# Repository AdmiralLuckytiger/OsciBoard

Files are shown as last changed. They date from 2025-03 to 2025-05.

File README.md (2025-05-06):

# __OsciBoard__: Wein Bridge Oscillator

<p align=center>
  
</p>

## 👋 Welcome

This repository walks you through the design, build, and testing process of a Wien Bridge Oscillator.

Inside, you'll find the steps we followed to bring the project to life, along with additional thoughts and notes added along the way. Since this has been an iterative process, we’ve included reflections and improvements made throughout the journey.

## 🎯 Objective

The goal of this project is to design and implement a sinusoidal oscillator operating at 10 kHz. To achieve this, we’ve chosen a classic Wien Bridge Oscillator as our base circuit. From there, the signal will be enhanced using a variable gain stage to improve performance and stability.

To analyze the oscillator’s output, we’ll be using a digital system. This means the signal needs to be conditioned and digitized before processing. For digitization, we'll use the ADC (Analog-to-Digital Converter) integrated in a System on Chip (SoC). This SoC includes:

- A programmable logic section (FPGA)

- Two microprocessors

Because of this setup, the oscillator's output voltage must remain within the 0 to 3.3V range to be safely read by the ADC. Protective measures will also be implemented to prevent any out-of-range voltages.

Once the signal is digitized, we aim to measure two key parameters:

- The frequency of the oscillation

- The amplitude of the waveform

The frequency value will be displayed on a 7-segment display connected via a shield to the development board.

## 🧪 Simulations
In this section, we describe the proposed system in more detail—breaking down the main stages and showing how we simulated each part. 

### 💡 Solution Overview
> [!IMPORTANT]
> We're required to use a Wien Bridge Oscillator as a constraint of this project.
> Fortunately, this type of oscillator is a great fit for our goals—it’s inexpensive, well-suited for our frequency range, and has a smooth startup behavior.

Our solution is built around a Wien Bridge Oscillator with adjustable gain. The oscillator generates a sinusoidal signal that is sent to two separate subcircuits:

---

### 🔎 Subcircuit 1: Frequency Measurement Path

This branch of the circuit is responsible for preparing the signal so that its frequency can be measured digitally: 

- First, a summing amplifier introduces an offset and scales the signal.

- Then, an inverting amplifier corrects the polarity, resulting in a signal fully within the positive range.

Together, these stages ensure the signal is properly conditioned for reliable digital processing.

---

### 🔎 Subcircuit 2: Amplitude Measurament Path

This second branch is dedicated to measuring the amplitude of the oscillation: 

- A precision full-wave rectifier caaptures the full waveform.

- This is followed by a two-pole low-pass filter, which smooths the signal to provide a stable DC value that reflects the original amplitude.

> [!WARNING]
> In this kind of project, where we're working with signals that carry important information, it's essential to use precision rectifiers—other types can significantly alter the signal. 

The solution we chose is based on generating two separate signals—one for measuring amplitude and the other for frequency. While this approach was selected somewhat arbitrarily, it gives us a great opportunity to implement and experiment with different circuits along the way.

> [!CAUTION]
> We could have gone with a normalized filter, like a Chebyshev filter. However, since we're not working in a restrictive environment and the only key requirement is unity gain, we chose this particular design. In the lab, other topologies ran into some issues with maintaining the correct gain. That said, future improvements could definitely benefit from using normalized filters for better performance.

<p align="center">
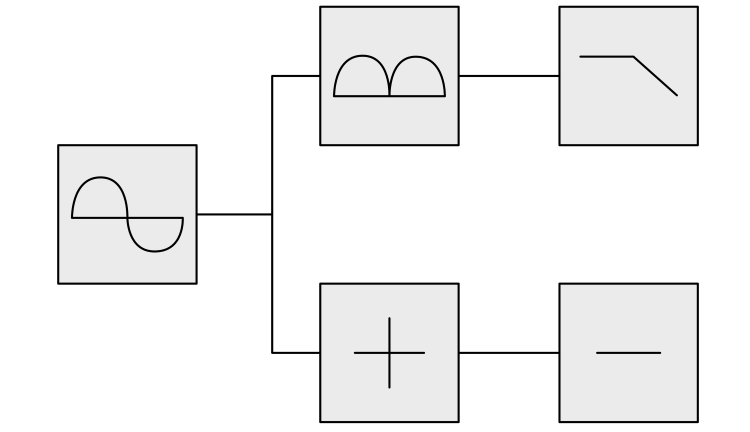
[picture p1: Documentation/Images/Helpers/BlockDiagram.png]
  
</p>

### 🖥️ Simulation Enviorament 

The entire system was simulated using LTSpice, a tool provided for free by Analog Devices. We chose LTSpice as our main simulation environment because it's free and includes most of the component models we’re using out of the box.

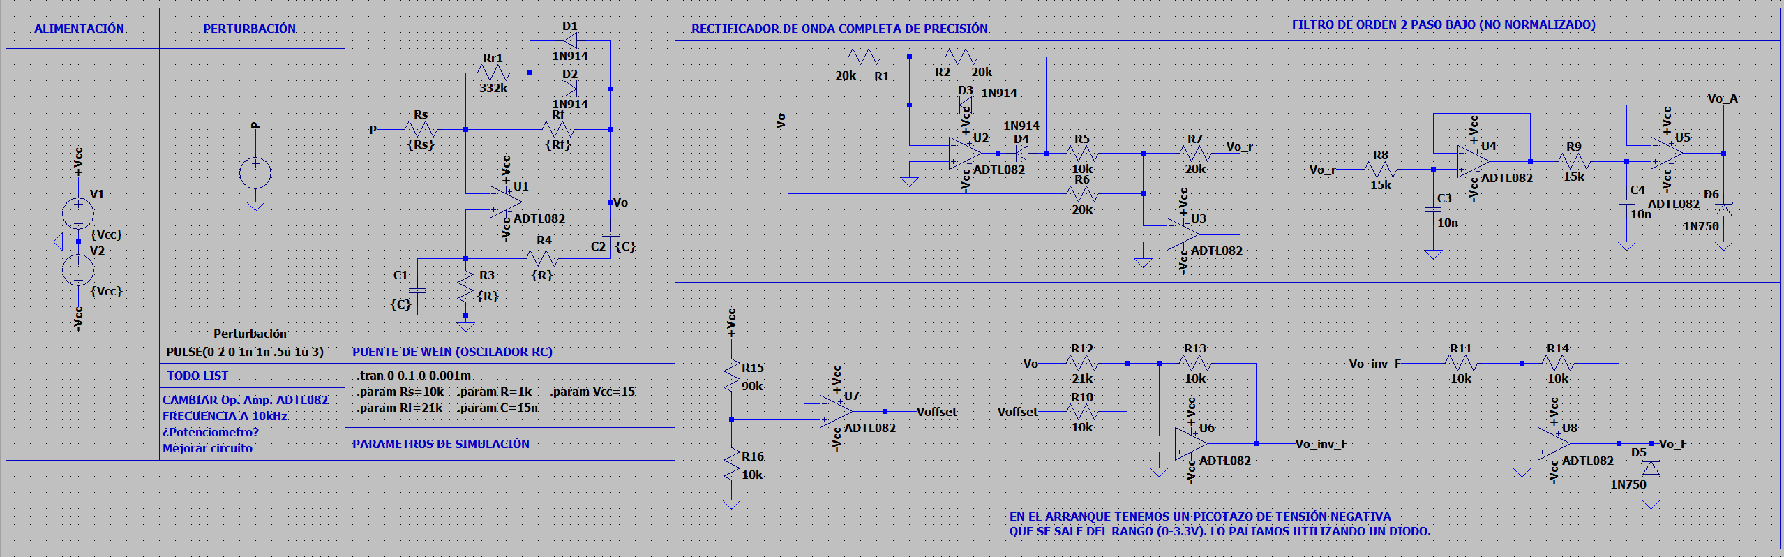
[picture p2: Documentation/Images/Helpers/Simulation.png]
Simulation Schema


> [!NOTE]
> The component values used in the simulation were selected through a combination of theoretical calculations and manual tuning. The theory we applied comes from "Fundamentals of Electronics: Oscillators and Advanced Electronics Topics."

### 🧾 Results

We identified three critical signals in the system:

- The output of the Wien Bridge Oscillator
- The frequency output signal
- The amplitude output signal

The simulation results for these signals are consistent with theoretical expectations.

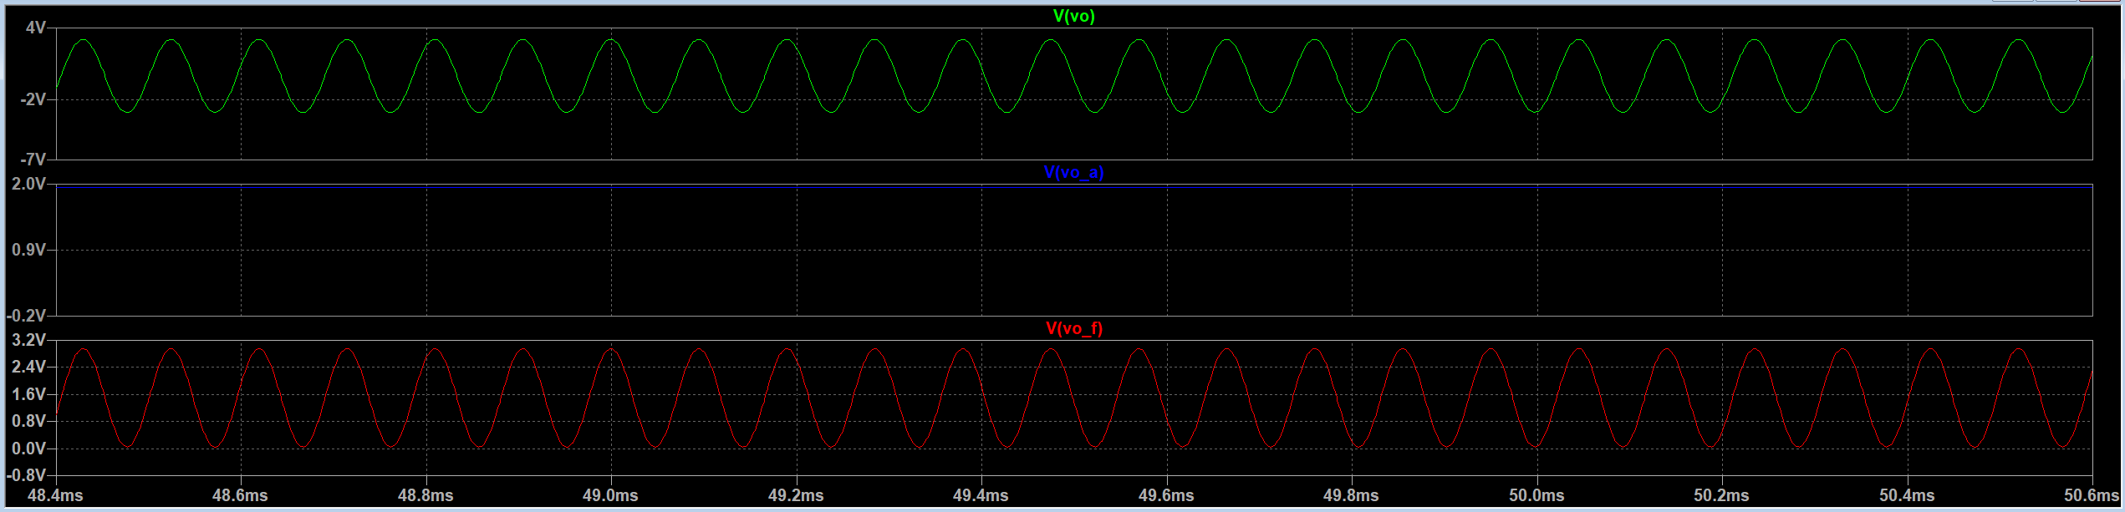
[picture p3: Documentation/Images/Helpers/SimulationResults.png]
Simulation Results


> [!NOTE]
> Beyond these main signals, the simulation also provided valuable insights through intermediary signals. These will be especially helpful when debugging the real-world circuit.

## 👨‍🔬 Lab Tests
Once the simulation was completed and validated according to the project specifications, we moved on to testing the core building blocks of our system. A full system test would have required significantly more time and resources, and the errors we could catch with a complete system weren’t considered critical. 

> [!NOTE]
> In our first approach, we focused only on testing the Wien Bridge Oscillator. However, this decision led us to miss some issues in the full-wave precision rectifier block before sending the schematics out for fabrication. That ended up being a mistake and taught us a valuable lesson—future projects should definitely include testing of all critical blocks early on.

### ✅ Wein Bridge Oscillator

Wein Bridge Oscillator

Without the variable gain circuit, the oscillator output was saturated and had no amplitude control, which made it unusable in its initial form.

### ✅ Full Wave Precission Rectifier

> [!NOTE]
> Our first version of this block used standard diodes, which introduced distortion into the signal. We solved this issue by switching to Schottky diodes with a fast recovery time, which worked much better in this case.

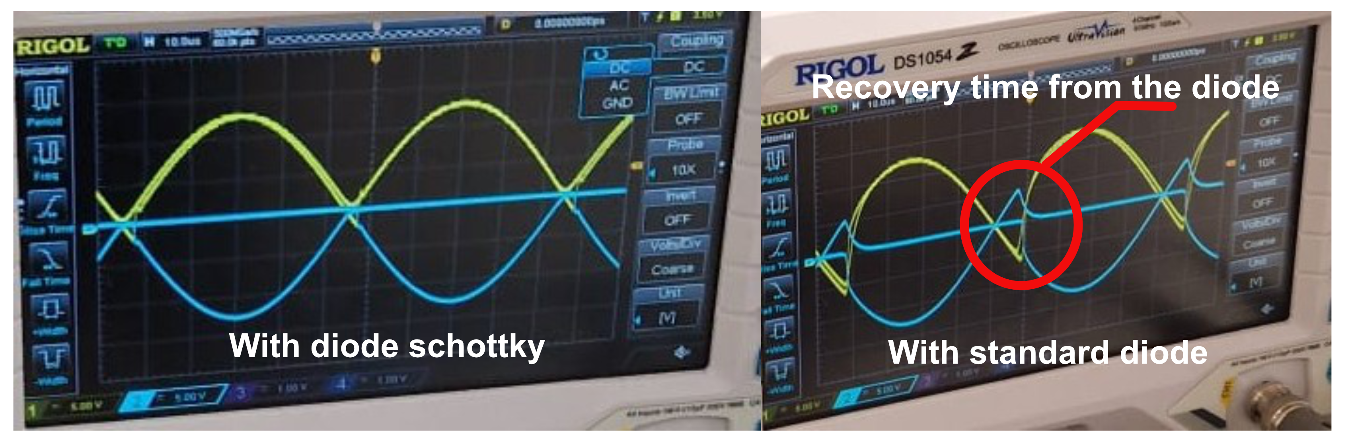
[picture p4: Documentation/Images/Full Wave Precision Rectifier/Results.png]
Rectifier


## ▶️ PCB Design
This step was developed in parallel with the lab testing phase. We chose KiCad 8 for the PCB design because it’s a user-friendly tool that fits well with the scope of our project.

> [!NOTE]
> While KiCad’s documentation is excellent, we also used the book "Design an RP2040 Board with KiCad" as our primary guide throughout the design process.
---
### ✅ Schematics
We translated the schematics from our simulation into KiCad's tool. This step also gave us the opportunity to:

- Annotate key design aspects
- Select the appropriate component footprints, which helped with our component selection
- Approach the project more formally

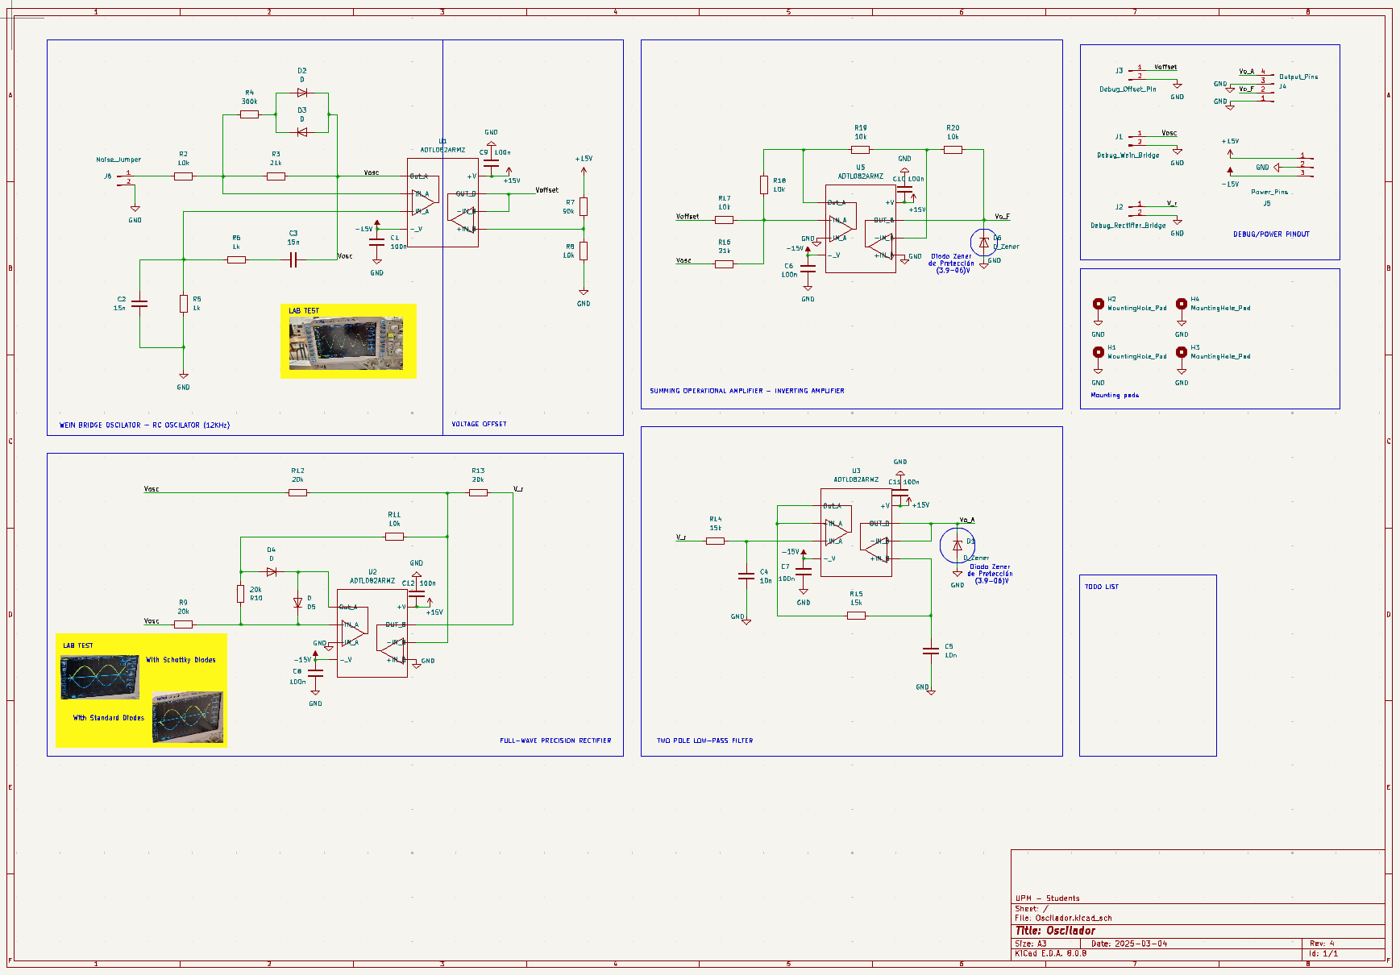
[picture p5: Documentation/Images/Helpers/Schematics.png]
Genenral Schematic

---
### ✅ Layout
The PCB layout is just as important as the schematics. For this part, we took an iterative approach, making small improvements and corrections with each step.

We added as many debug pins as possible to improve the system's observability. 

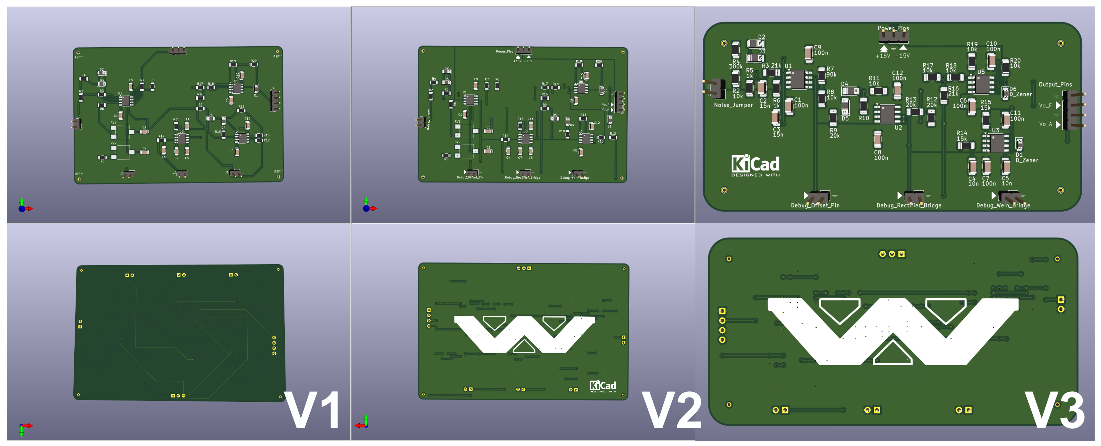
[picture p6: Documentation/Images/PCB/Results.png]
Layout


> [!CAUTION]
> A mistake worth highlighting is our use of non-standard debug pins. This could potentially cause short circuits when measuring with oscilloscope probes. In future designs, we’ll use standard debug pin layouts to make debugging easier and safer. 

> [!NOTE]
> Before starting the layout, it’s important to consider the manufacturer’s capabilities. Certain design parameters, such as trace width or via size, may be limited by the manufacturer, so it's a good idea to choose them early in the process.

We also made use of flooded zones, which helped with power pin connections and provided some shielding for noise-sensitive components.

> [!NOTE]
> In future designs, we plan to avoid placing vias on the component pads, as it negatively affects the quality of solder connections.
---
### ✅ Components Selection
Since we’re hand-soldering the components ourselves, we limited our selection to standardized 1206 and 0805 footprints, which are easier to solder manually. 

> [!IMPORTANT]
> When working with circuits where component values are critical, we recommend testing a range of values. Despite validating component values on a breadboard, one of our resistors had a tolerance issue in the final PCB version, which caused the Wien Bridge Oscillator to fail. This issue wasn’t caught until after over eight hours of debugging—a painful lesson that we hope to avoid in future projects. 
---
#### 💰 Purchase
For simplicity, we sourced all our components from a single electronics shop.

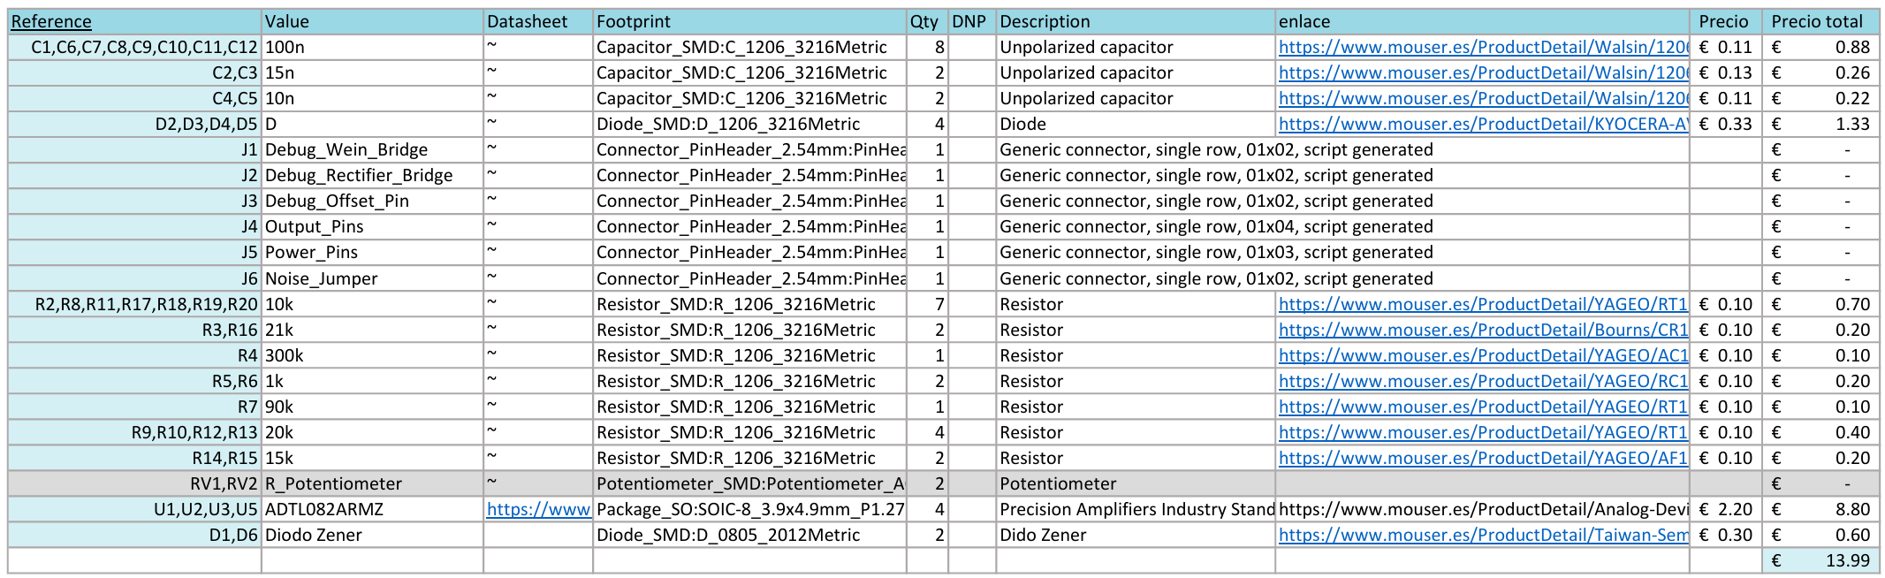
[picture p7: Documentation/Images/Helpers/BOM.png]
BOM


> [!NOTE]
> Before making any purchases, make sure the shop handles taxes. It can save you from unexpected costs down the road. 

## 🎉 Results
In the following images, you can see the board being tested. 

Lab Results

---

## 🧠 Digital Circuit Overview

A core component of this project is the development of a custom digital circuit deployed on the PYNQ-Z2 development board. This circuit is responsible for measuring and displaying the frequency of an input signal. It operates synchronously using the board’s external 125 MHz clock source.

### ⚙️ Core Functional Blocks

- **XADC**  
  The Xilinx Analog-to-Digital Converter (XADC) is used to sample the analog input signal. The IP core is configured to operate at 1 MSPS (Mega Samples Per Second), which provides sufficient resolution to support the frequency measurement system.

- **Frequency Counter**  
  A dedicated module counts the number of signal transitions (edges) within a fixed time window of 0.1 seconds. This interval allows us to display the frequency in kilohertz (kHz) with two decimal places of precision.

- **Binary to Binary-Coded Decimal (BCD) Converter**  
  To prepare the computed frequency value for display, a binary-to-BCD converter is implemented using the Double Dabble algorithm. This conversion is necessary for driving human-readable outputs like 7-segment displays.

- **Display Interface**  
  The BCD-encoded frequency value is passed to a display driver that outputs it via 7-segment displays, allowing for visualization of the measured frequency.

---

### 📊 Simulation Results

Below are visual results from the simulations of each key subcircuit in the system. These illustrate the signal's journey from digitization to binary-coded decimal (BCD) conversion.

#### 🔍 XADC (Analog-to-Digital Conversion)

This image shows the output of the XADC operating at 1 MSPS with 100 samples per point. It represents the digitized version of the input analog signal.

<p align="center">
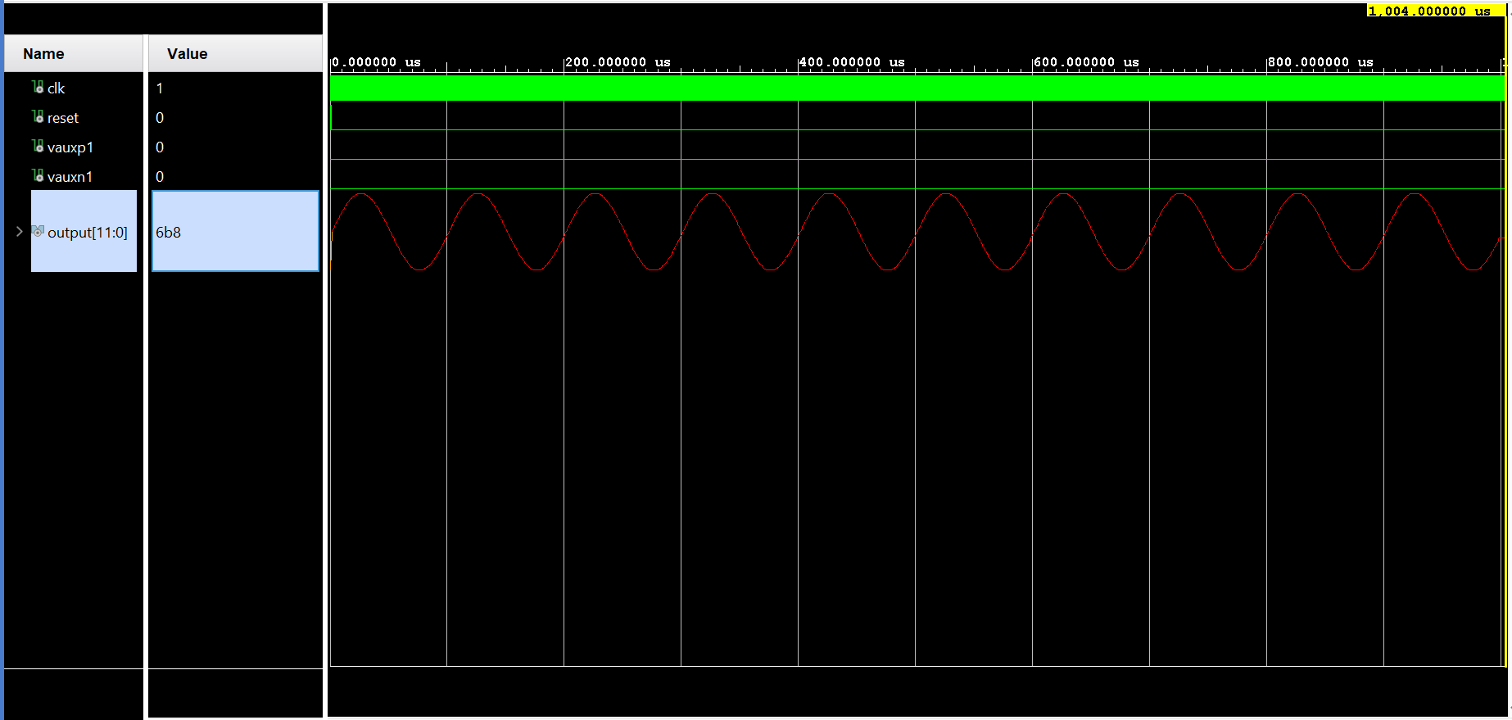
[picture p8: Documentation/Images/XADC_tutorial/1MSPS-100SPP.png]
  
</p>

#### 📟 Frequency Counter

These simulations depict the frequency counter circuit in action. The first image shows the primary frequency counting logic, while the second provides a complementary perspective of the counter’s operation.

<p align="center">
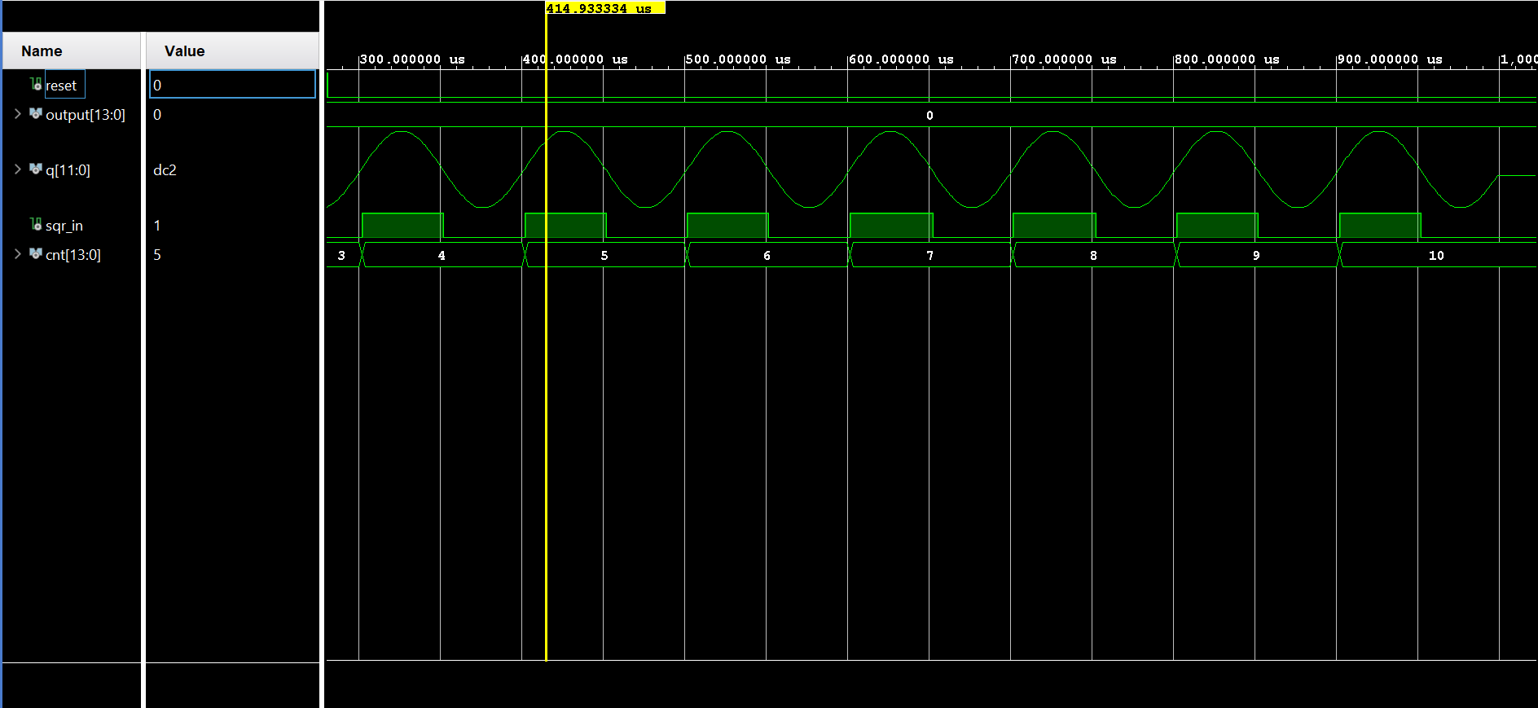
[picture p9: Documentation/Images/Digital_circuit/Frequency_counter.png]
  
</p>

<p align="center">
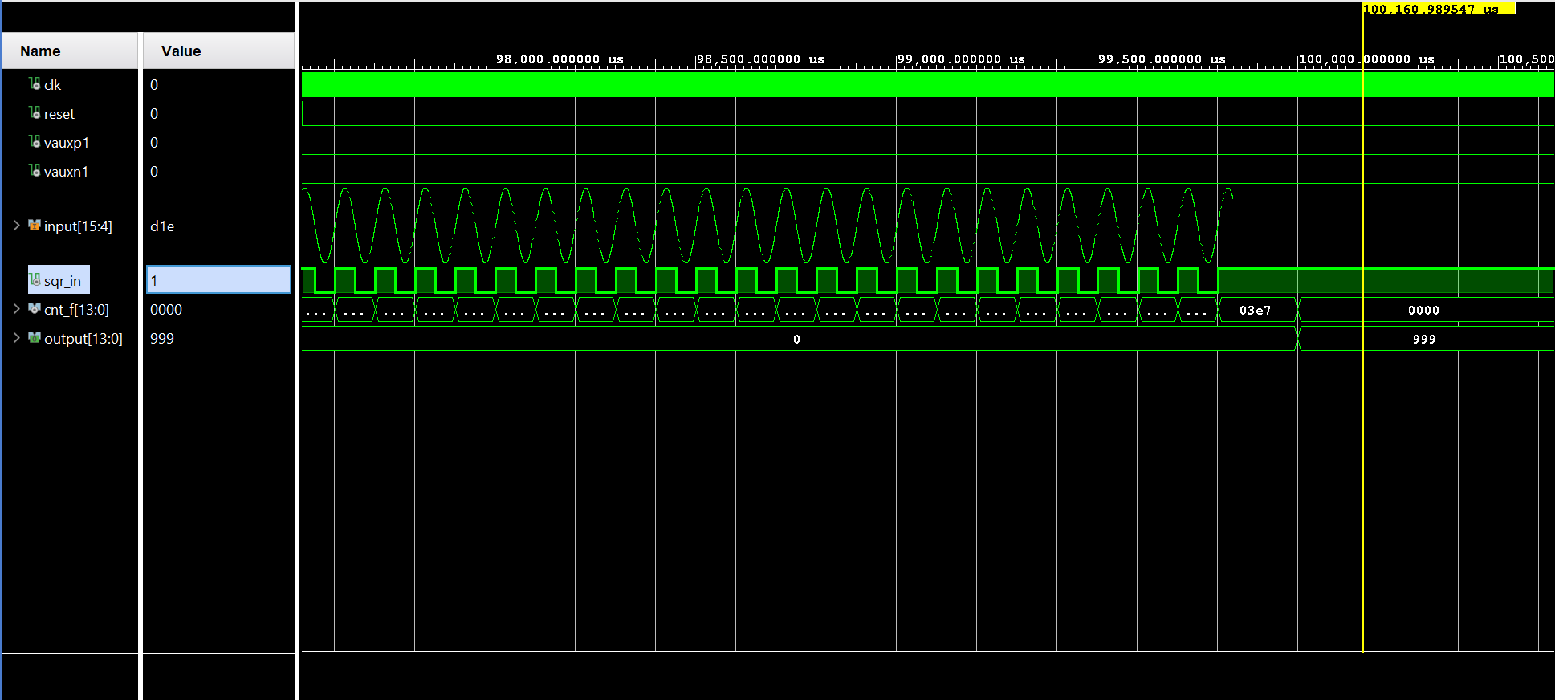
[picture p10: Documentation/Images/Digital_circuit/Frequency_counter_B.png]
  
</p>

#### 🔢 Binary to BCD Conversion

Finally, the image below demonstrates the output of the binary to BCD converter. This is the final step in the digital signal processing pipeline, converting the raw binary frequency value into a human-readable decimal format.

<p align="center">
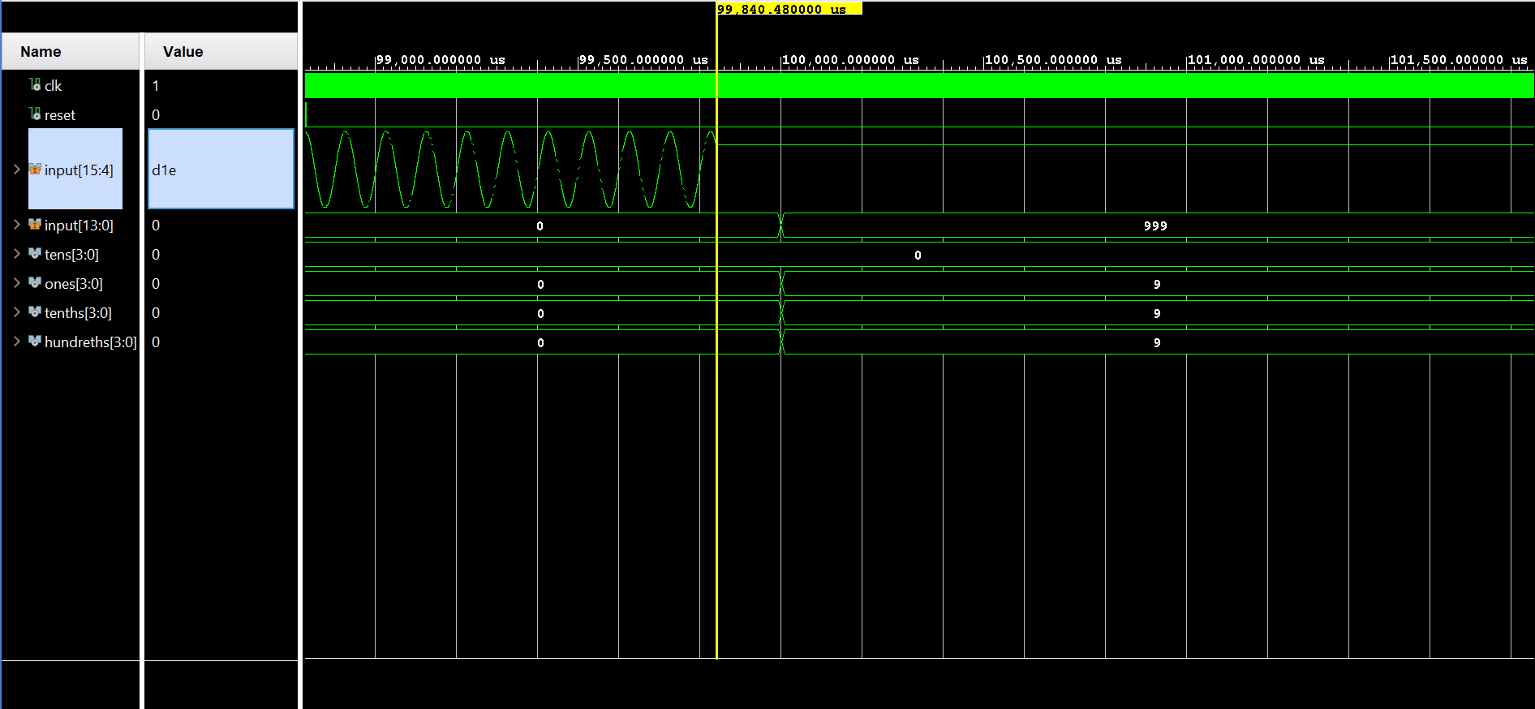
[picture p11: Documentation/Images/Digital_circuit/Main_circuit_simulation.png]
  
</p>

---

### 💡 Additional Notes

This system is entirely implemented in VHDL and synthesized using Xilinx Vivado. For detailed implementation instructions, configuration parameters, and deployment steps, refer to the [project documentation](./Prototype/Vivado/README.md).

---

## 🎉 Results 

The image below showcases our digital circuit in action, measuring the frequency of a sinusoidal signal generated by the Wien Bridge oscillator board.

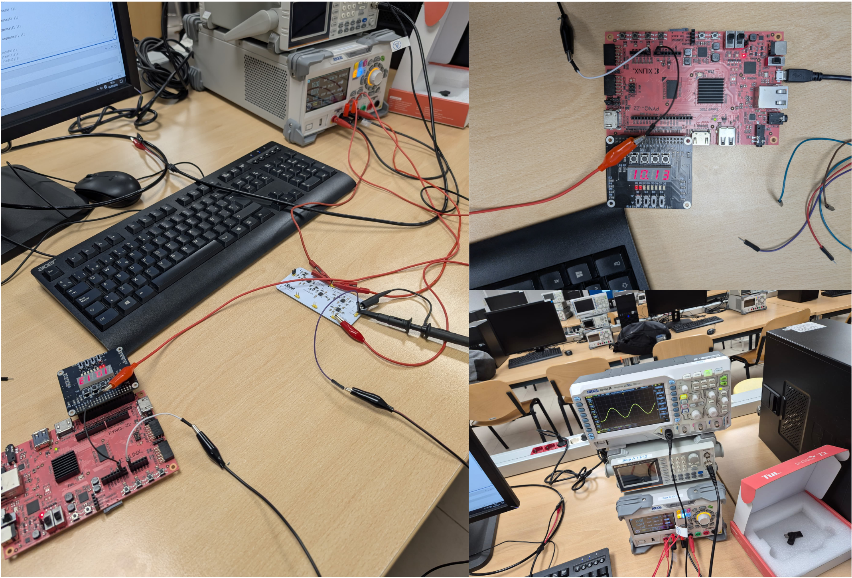
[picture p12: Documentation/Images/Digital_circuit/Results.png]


In this setup, the Wien Bridge oscillator produces a stable sine wave, which is then processed by our digital circuit to determine its frequency.

As a final note, we would like to highlight the success of integrating both digital and analog circuitry in our project. This experience has provided us with invaluable insights into working across both domains, and has significantly increased our confidence in designing and implementing mixed-signal systems.

That said, throughout the development process, we also identified areas for improvement and noted several design mistakes that can be corrected in future iterations. These lessons will be crucial for refining our approach and achieving even better results in upcoming projects.

---

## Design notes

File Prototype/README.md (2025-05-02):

### 📁 Project Files Overview

In this folder, you will find the primary prototype files created using **KiCad 8**. These files can be used to generate the necessary **Gerber files** required for PCB manufacturing.

Additionally, the folder includes:

* 💡 **Digital circuit design source files** – Schematics and layouts for the digital components of the project.
* 🧪 **Testbenches** – Simulation files used to verify the behavior and performance of individual subcircuits.

These resources collectively support both the hardware prototyping and digital logic development aspects of the project.

---

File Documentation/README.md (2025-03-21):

# Main documentation
In this folder you can find different versions of the schematics of the proyect, images and the request with which we start the proyect.

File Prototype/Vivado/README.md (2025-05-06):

# 🧭 Digital Circuit Design

Before jumping into implementation, it's essential to address a few design questions that guide our development choices. These questions will help shape the architecture of the digital circuit and ensure it meets performance and usability expectations.

---

## 🧠 How will we measure the frequency of the sinusoidal signal from the XADC?

The XADC (Xilinx Analog-to-Digital Converter) gives us a digitized version of the input analog signal. However, to determine the frequency, we must process that data further.

A straightforward and effective method is to use a [frequency counter](https://andybrown.me.uk/2016/02/21/nanocounter/). The idea is to:

- Convert the analog sinusoid to a square wave (e.g., by thresholding).
- Count the number of cycles of the square wave in a given time frame.
- Compare this with a known clock signal to compute frequency.

This approach is hardware-friendly and works well in real-time digital systems.

> [!WARNING]
> When using the XADC, be careful with the pins you select. Take the time to thoroughly check the schematics of your specific board and consult the official constraints file. Sometimes, pin names can be misleading.

---

## 🔢 How do we display binary numbers on 7-segment displays?

The frequency counter outputs binary values that aren't human-readable in their raw form. To make these values suitable for display, we’ll convert them into [Binary-Coded Decimal (BCD)](https://en.wikipedia.org/wiki/Binary-coded_decimal).

BCD makes it easier to display numbers on standard 7-segment displays, which are designed for decimal digits.

### Conversion Method

To perform this conversion in hardware, we use the [Double Dabble algorithm](https://en.wikipedia.org/wiki/Double_dabble). It's a simple and effective way to convert binary values into BCD, with low resource usage — perfect for FPGA implementation.

The output will then drive four 7-segment displays, allowing easy real-time monitoring.

---

## ⏱️ What sampling rate do we need?

We are working with a signal approximately **10 kHz** in frequency. To capture the waveform accurately:

- **Minimum sampling rate:** 20 kHz (according to the **Nyquist Theorem**).
- In practice, a higher rate (e.g., 50–100 kHz) might be used to improve accuracy and reliability.

> [!NOTE]  
> **Nyquist Theorem**  
> If a function contains no frequencies higher than BW Hz, it is completely determined by samples taken every 1/(2BW) seconds.

Beyond the basic concept of sampling frequency, it's important to emphasize that, for our frequency counter, we require the highest possible number of samples per second. This is crucial because we need to accurately capture the smooth transitions of the signal, especially as it crosses our reference threshold of 1.5V (the virtual ground or zero reference).

Accurate detection of these transitions is essential for reliable frequency measurement. A higher sampling rate allows us to pinpoint the exact moments when the signal crosses the reference voltage, minimizing errors due to aliasing or missed transitions.

In the following images, we compare different sampling scenarios to illustrate the challenges and implications of insufficient sampling resolution. 

<p align="center">
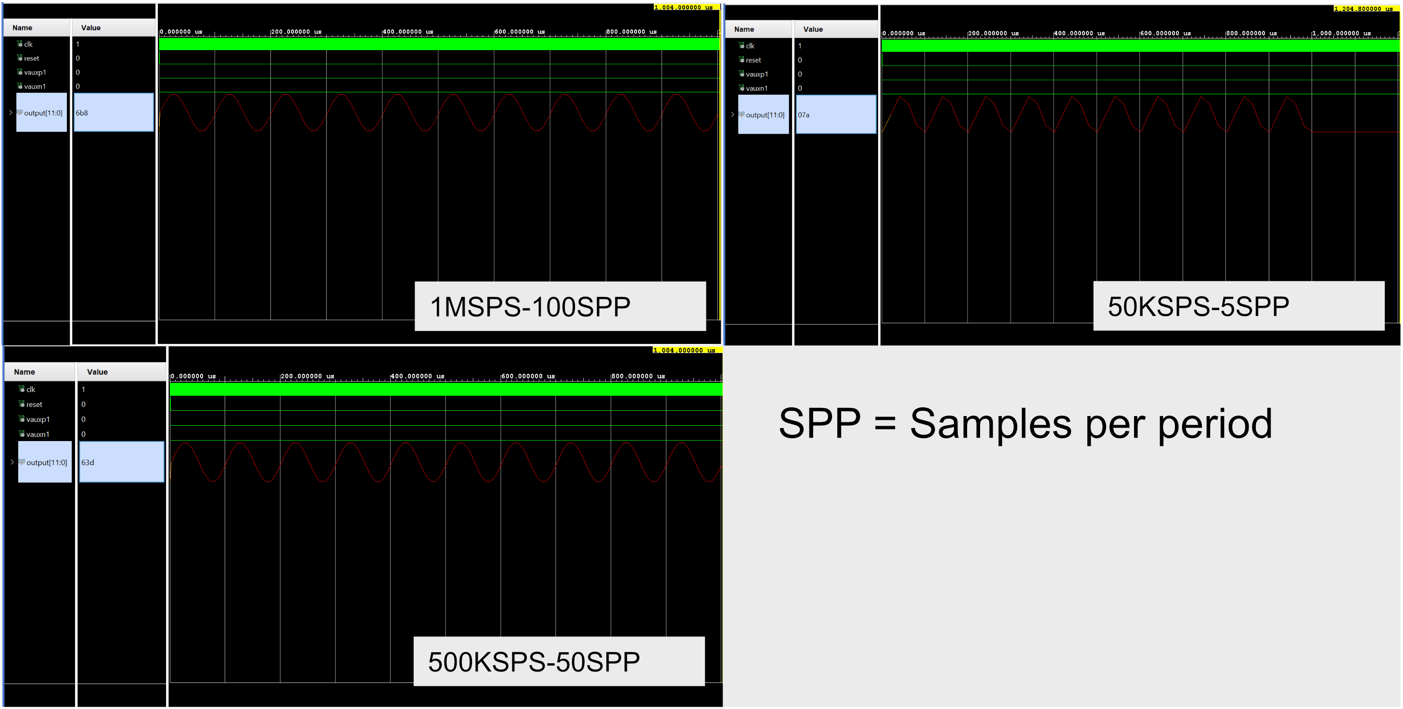
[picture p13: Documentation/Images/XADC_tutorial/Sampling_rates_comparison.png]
  
</p>

---

## ⚙️ At what frequency will the digital circuit operate?

This project is designed to be deployed on the PYNQ-Z2 development board, which features an external 125 MHz clock source. As a result, our synchronous digital circuit will operate using this 125 MHz clock signal as its primary timing reference. 

> [!Note]
> If a different operating frequency is desired, we can make use of the Clocking Wizard IP core available in Vivado. This tool allows us to generate derived clock signals within a configurable range, enabling greater flexibility in timing and design optimization.

---

## 📡 How do we communicate with the XADC?

Communication with the XADC is done via the **Dynamic Reconfiguration Port (DRP)**. This port allows us to:

- Read samples from the analog input channels.
- Configure parameters such as sampling rate and averaging.
- Monitor internal signals like temperature or supply voltage if needed.

### Helpful Resources

- [Dynamic Reconfiguration Port Documentation](https://docs.amd.com/r/en-US/pg165-cmac/Dynamic-Reconfiguration-Port)  
- [XADC User Guide for 7 Series FPGAs and Zynq-7000 SoC](https://docs.amd.com/r/en-US/ug480_7Series_XADC)

---

## 🚧 What's next?

The next steps in this project include:

1. **Implementing the frequency counter** in VHDL.
2. **Designing the binary-to-BCD converter** using Double Dabble and VHDL.
3. **Driving the 7-segment display** to visualize the signal frequency.
4. **Integrating with the XADC** using the DRP.

---

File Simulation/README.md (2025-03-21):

# Simulation files
In this folder you could find the simulation file of the whole proyect. It contains enough comments and structure based on blocks that we expect to help the interpretation.

Simulatio Overview

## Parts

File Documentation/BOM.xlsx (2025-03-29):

Reference | Value | Datasheet | Footprint | Qty | DNP | Description | enlace | Precio | Precio total |  | Pedido | Estado | revisión
C1,C6,C7,C8,C9,C10,C11,C12 | 100n | ~ | Capacitor_SMD:C_1206_3216Metric | 8 |  | Unpolarized capacitor | https://www.mouser.es/ProductDetail/Walsin/1206B104K500CT | €0.11 | €0.88 | S | Sí | Entregado | si
C2,C3 | 15n | ~ | Capacitor_SMD:C_1206_3216Metric | 2 |  | Unpolarized capacitor | https://www.mouser.es/ProductDetail/Walsin/1206B153K250CT?qs=sGAEpiMZZMuMW9TJLBQkXlzjw5uhdiuX6fd6WKOufTo%3D | €0.13 | €0.26 | S | Sí | Entregado | si
C4,C5 | 10n | ~ | Capacitor_SMD:C_1206_3216Metric | 2 |  | Unpolarized capacitor | https://www.mouser.es/ProductDetail/Walsin/1206B103K631CT | €0.11 | €0.22 | S | Sí | Entregado | si
D2,D3,D4,D5 | D | ~ | Diode_SMD:D_1206_3216Metric | 4 |  | Diode | https://www.mouser.es/ProductDetail/KYOCERA-AVX/SD1206S040S1R0?qs=jCA%252BPfw4LHZ%2FRBugmNm8zw%3D%3D | €0.33 | €1.33 | S | Sí | Entregado | si
J1 | Debug_Wein_Bridge | ~ | Connector_PinHeader_2.54mm:PinHeader_1x02_P2.54mm_Vertical | 1 |  | Generic connector, single row, 01x02, script generated |  |  | €0.00 |  |  | En Stock | si
J2 | Debug_Rectifier_Bridge | ~ | Connector_PinHeader_2.54mm:PinHeader_1x02_P2.54mm_Vertical | 1 |  | Generic connector, single row, 01x02, script generated |  |  | €0.00 |  |  | En Stock | si
J3 | Debug_Offset_Pin | ~ | Connector_PinHeader_2.54mm:PinHeader_1x02_P2.54mm_Vertical | 1 |  | Generic connector, single row, 01x02, script generated |  |  | €0.00 |  |  | En Stock | si
J4 | Output_Pins | ~ | Connector_PinHeader_2.54mm:PinHeader_1x04_P2.54mm_Vertical | 1 |  | Generic connector, single row, 01x04, script generated |  |  | €0.00 |  |  | En Stock | si
J5 | Power_Pins | ~ | Connector_PinHeader_2.54mm:PinHeader_1x03_P2.54mm_Vertical | 1 |  | Generic connector, single row, 01x03, script generated |  |  | €0.00 |  |  | En Stock | si
J6 | Noise_Jumper | ~ | Connector_PinHeader_2.54mm:PinHeader_1x02_P2.54mm_Vertical | 1 |  | Generic connector, single row, 01x02, script generated |  |  | €0.00 |  |  | En Stock | si
R2,R8,R11,R17,R18,R19,R20 | 10k | ~ | Resistor_SMD:R_1206_3216Metric | 7 |  | Resistor | https://www.mouser.es/ProductDetail/YAGEO/RT1206FRE0710KL?qs=sGAEpiMZZMtlubZbdhIBILjYW2Gkblj8eHt9HKO7Or0%3D | €0.10 | €0.70 | S | Sí | Entregado | si
R3,R16 | 21k | ~ | Resistor_SMD:R_1206_3216Metric | 2 |  | Resistor | https://www.mouser.es/ProductDetail/Bourns/CR1206-FX-2102ELF?qs=sGAEpiMZZMtlubZbdhIBIPXF8FEETpZctezP1zqKo10%3D | €0.10 | €0.20 | S | Sí | Entregado | si, Modificada a 22KOhms
R4 | 300k | ~ | Resistor_SMD:R_1206_3216Metric | 1 |  | Resistor | https://www.mouser.es/ProductDetail/YAGEO/AC1206FR-07330KL?qs=yhV1fb9g%2FKavn5cKIWcPHg%3D%3D | €0.10 | €0.10 | S | Sí | Entregado | si
R5,R6 | 1k | ~ | Resistor_SMD:R_1206_3216Metric | 2 |  | Resistor | https://www.mouser.es/ProductDetail/YAGEO/RC1206JR-071KP | €0.10 | €0.20 | S | Sí | Entregado | si
R7 | 90k | ~ | Resistor_SMD:R_1206_3216Metric | 1 |  | Resistor | https://www.mouser.es/ProductDetail/YAGEO/RT1206DRE0790KL?qs=NgbZBzc1CyEoLHe57MF17w%3D%3D | €0.10 | €0.10 | S | Sí | Entregado | si
R9,R10,R12,R13 | 20k | ~ | Resistor_SMD:R_1206_3216Metric | 4 |  | Resistor | https://www.mouser.es/ProductDetail/YAGEO/RT1206FRD0720KL?qs=k2KEx2DUIRQ%2Ff9JHz%2FfmgQ%3D%3D | €0.10 | €0.40 | S | Sí | Entregado | si
R14,R15 | 15k | ~ | Resistor_SMD:R_1206_3216Metric | 2 |  | Resistor | https://www.mouser.es/ProductDetail/YAGEO/AF1206JR-0715KL?qs=1mbolxNpo8dXtUKGVM6usQ%3D%3D | €0.10 | €0.20 | S | Sí | Entregado | si
RV1,RV2 | R_Potentiometer | ~ | Potentiometer_SMD:Potentiometer_ACP_CA6-VSMD_Vertical | 2 |  | Potentiometer |  |  | €0.00 | X | - | -
U1,U2,U3,U5 | ADTL082ARMZ | https://www.mouser.co.uk/datasheet/2/609/ADTL082_084-1503470.pdf | Package_SO:SOIC-8_3.9x4.9mm_P1.27mm | 4 |  | Precision Amplifiers Industry Standard TL082 | https://www.mouser.es/ProductDetail/Analog-Devices/ADTL082ARZ?qs=WIvQP4zGangG9ueGPyeJRQ%3D%3D | €2.20 | €8.80 | s | Sí | Entregado | si
D1,D6 | Diodo Zener |  | Diode_SMD:D_0805_2012Metric | 2 |  | Dido Zener | https://www.mouser.es/ProductDetail/Taiwan-Semiconductor/BZY55B3V3-RBG?qs=mAH9sUMRCtvrJdI%2FtfeTug%3D%3D | €0.30 | €0.60 | S | Sí | Entregado | si
 |  |  |  |  |  |  |  |  | €13.99

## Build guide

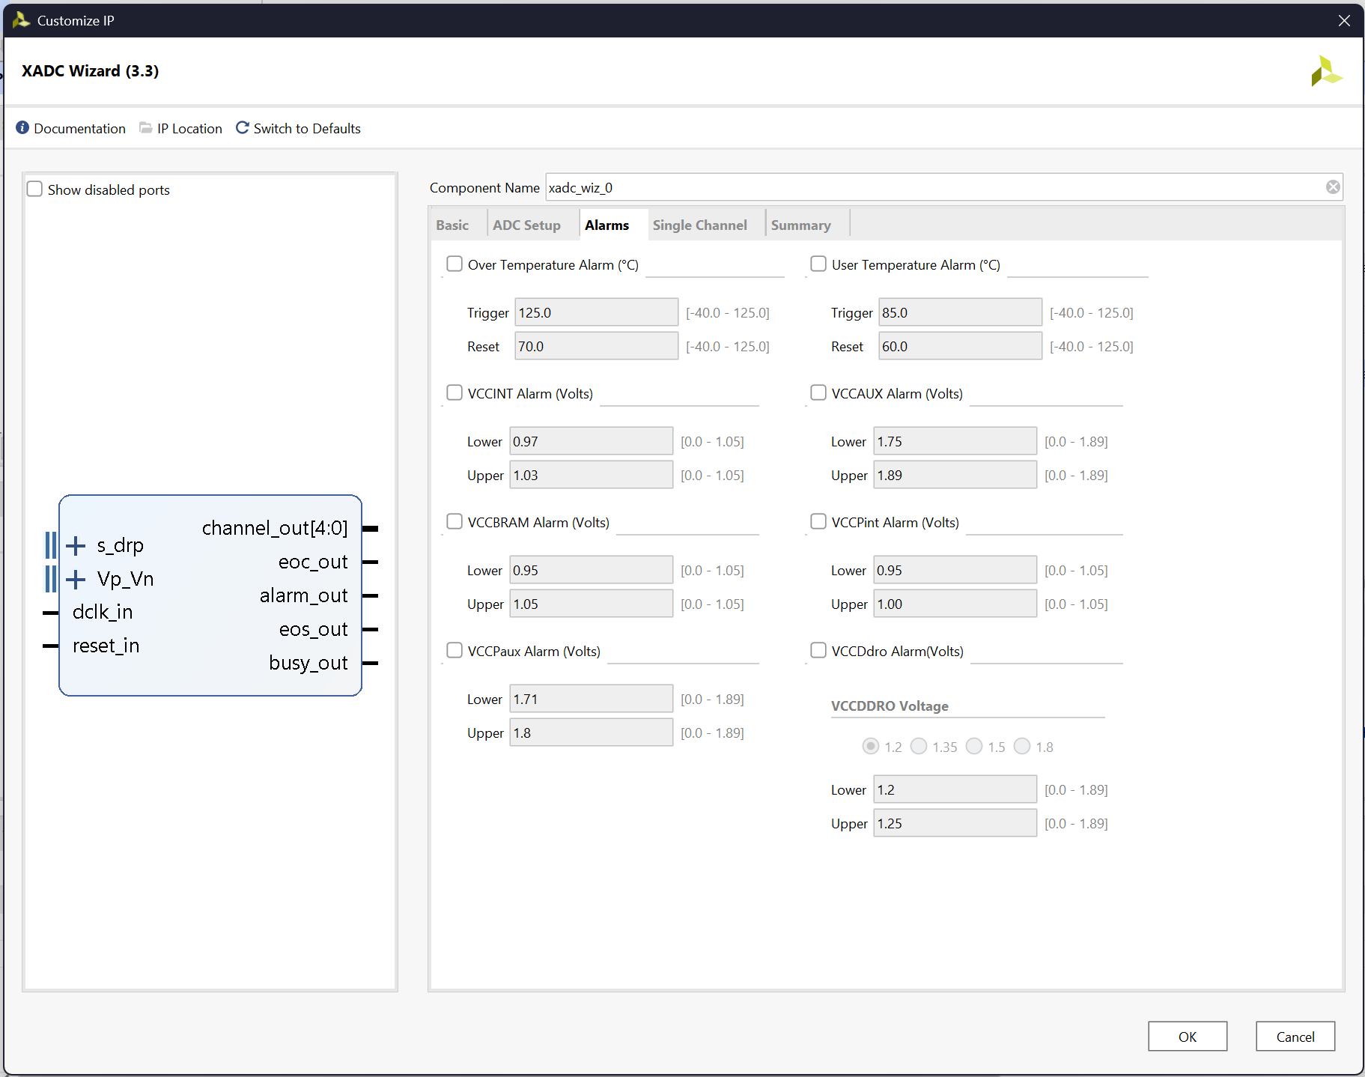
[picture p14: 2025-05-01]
Documentation/Images/XADC_tutorial/Step_2D.png

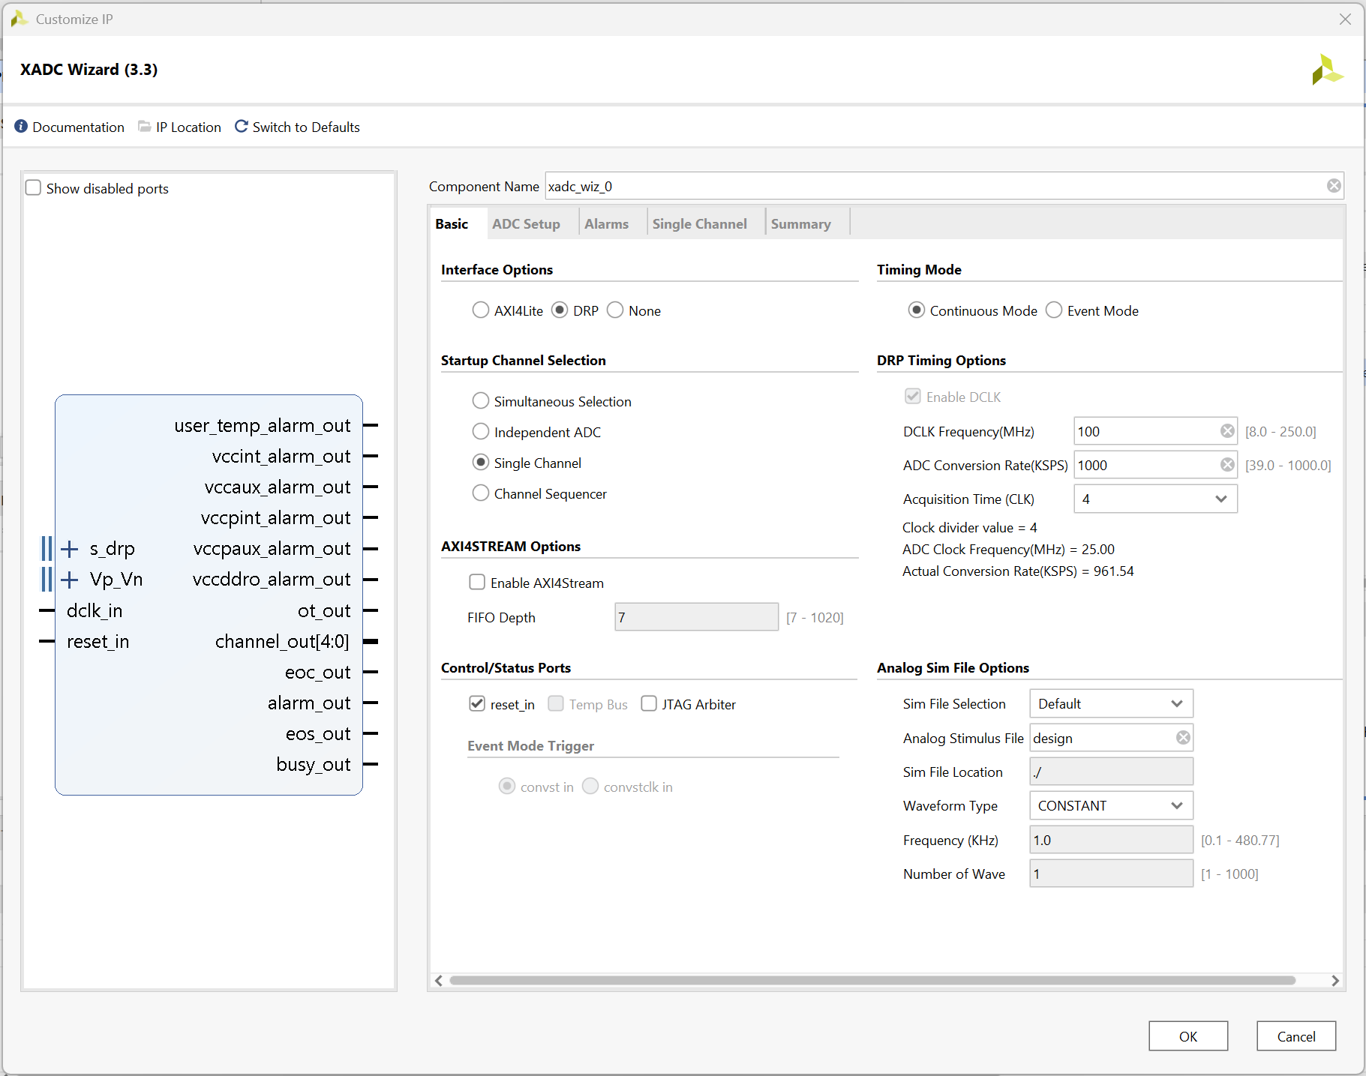
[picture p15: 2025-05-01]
Documentation/Images/XADC_tutorial/Step_2A.png

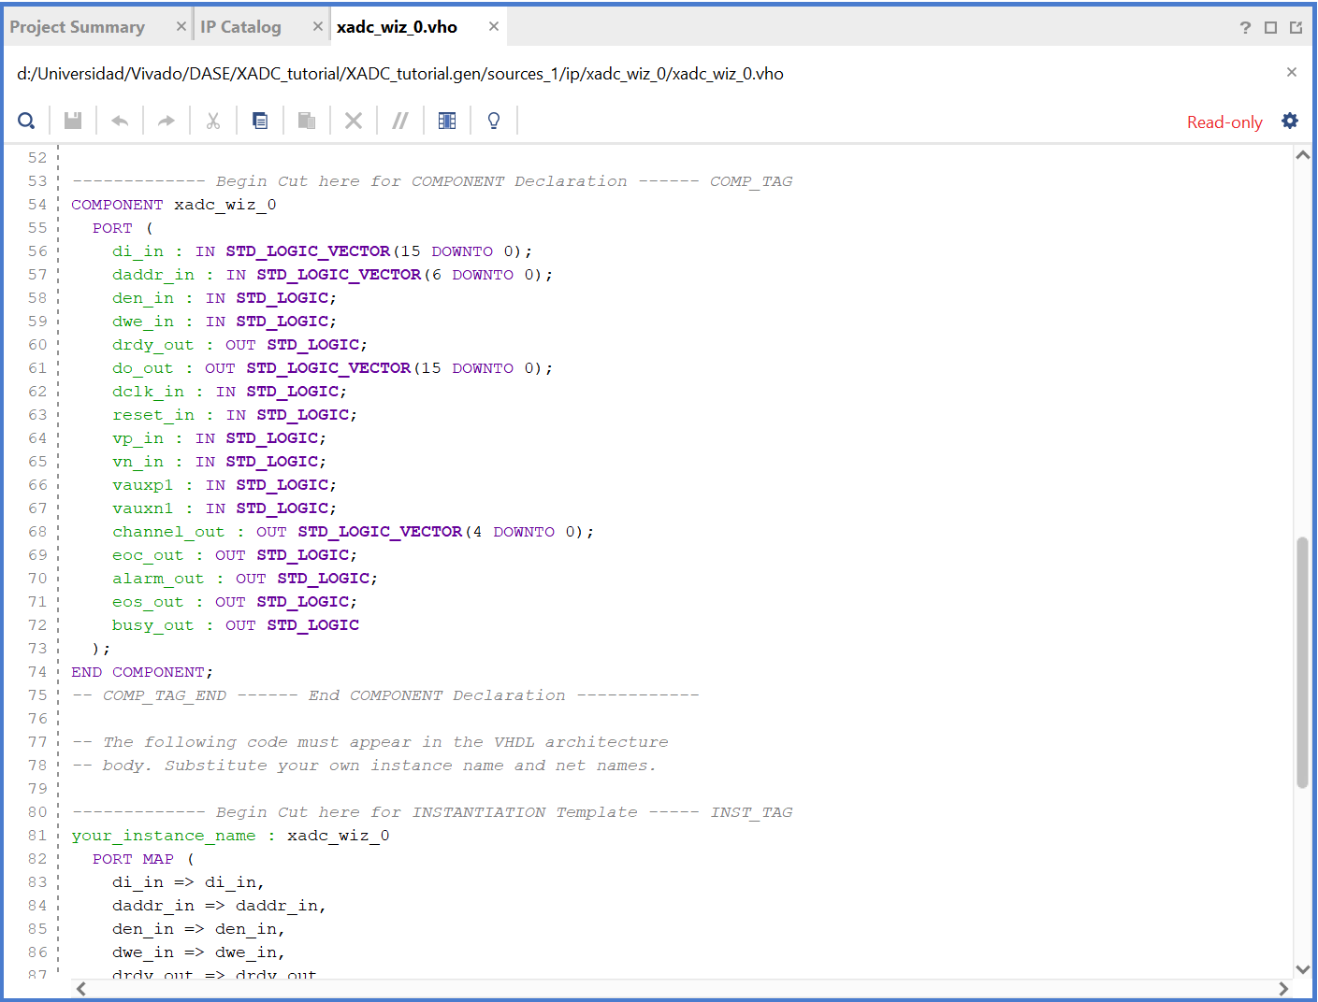
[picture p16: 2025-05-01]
Documentation/Images/XADC_tutorial/Step_4D.png

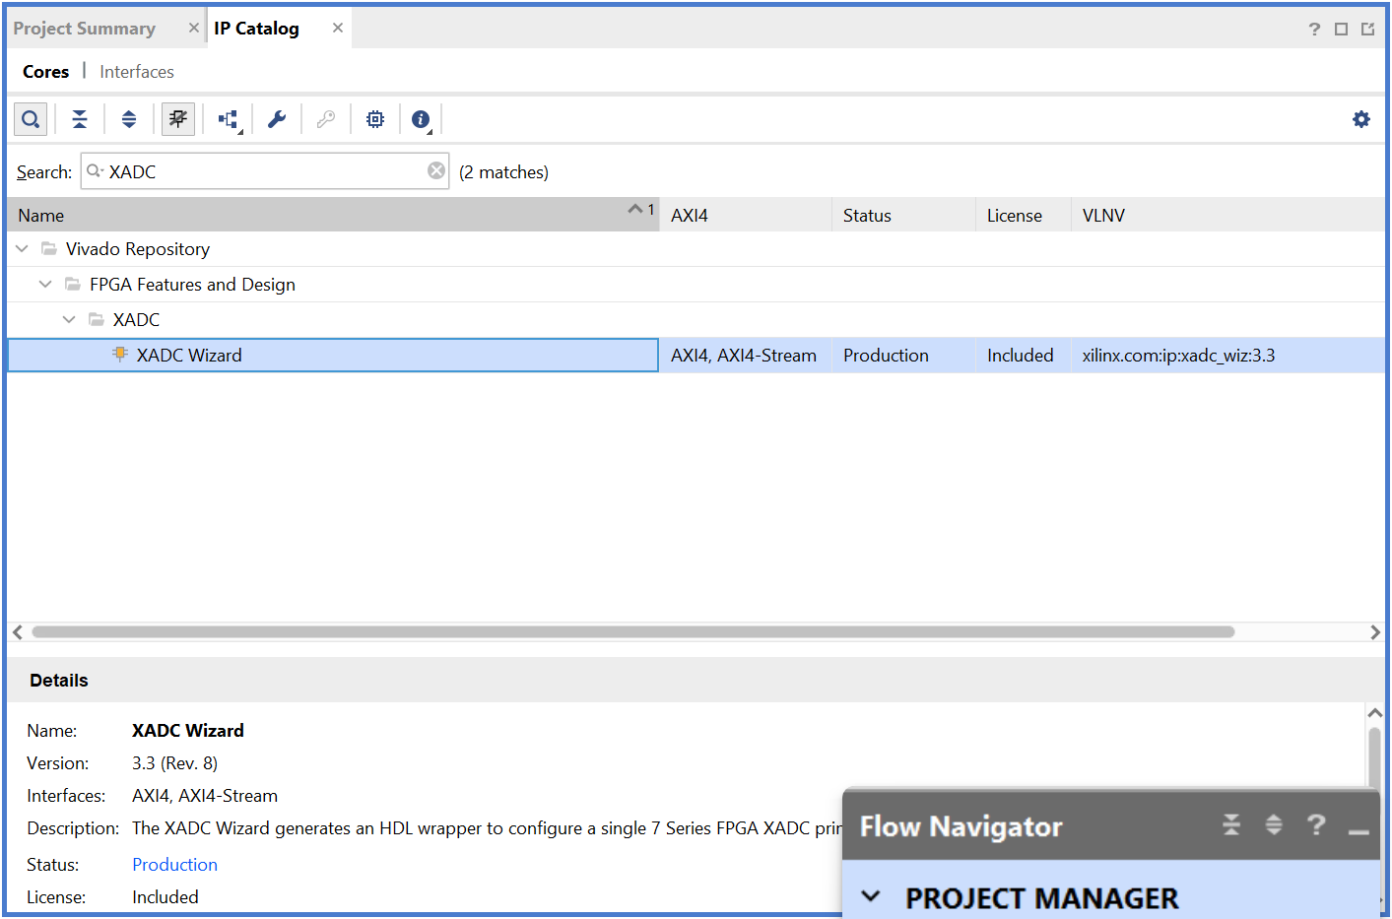
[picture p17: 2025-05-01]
Documentation/Images/XADC_tutorial/Step_1B.png

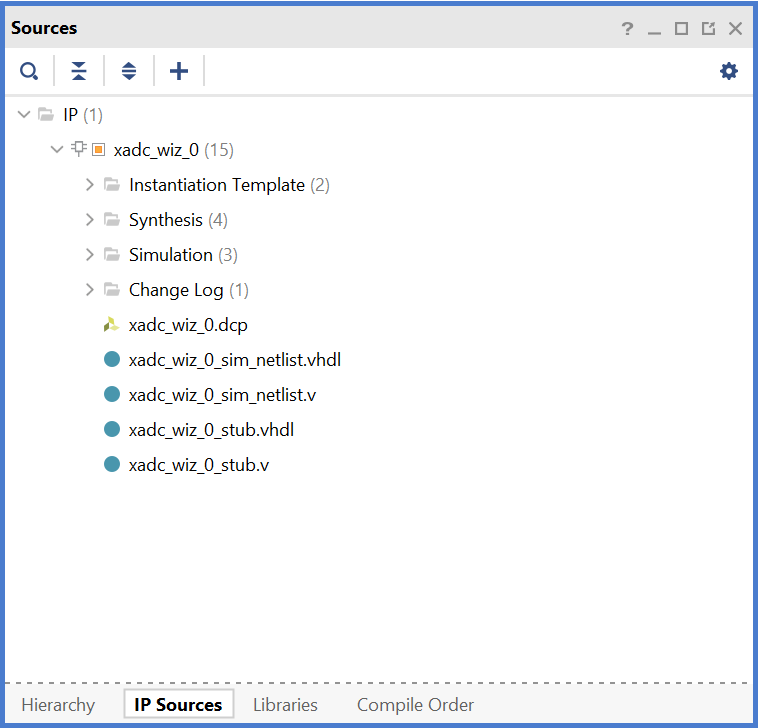
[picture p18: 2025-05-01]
Documentation/Images/XADC_tutorial/Step_4B.png

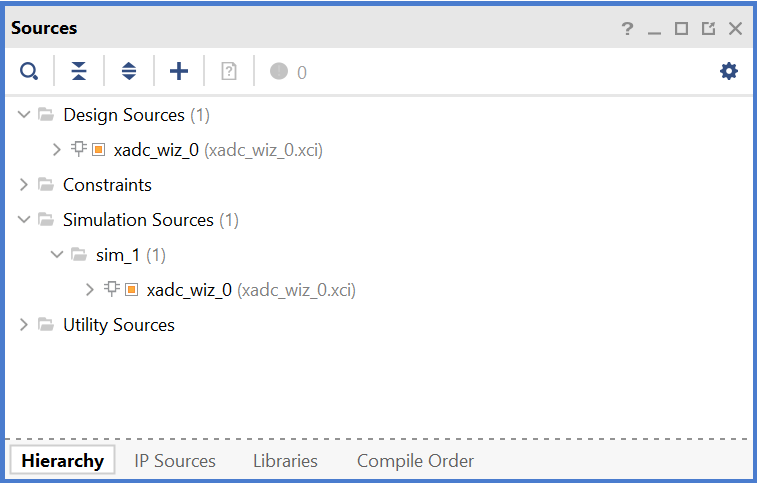
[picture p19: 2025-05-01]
Documentation/Images/XADC_tutorial/Step_4A.png

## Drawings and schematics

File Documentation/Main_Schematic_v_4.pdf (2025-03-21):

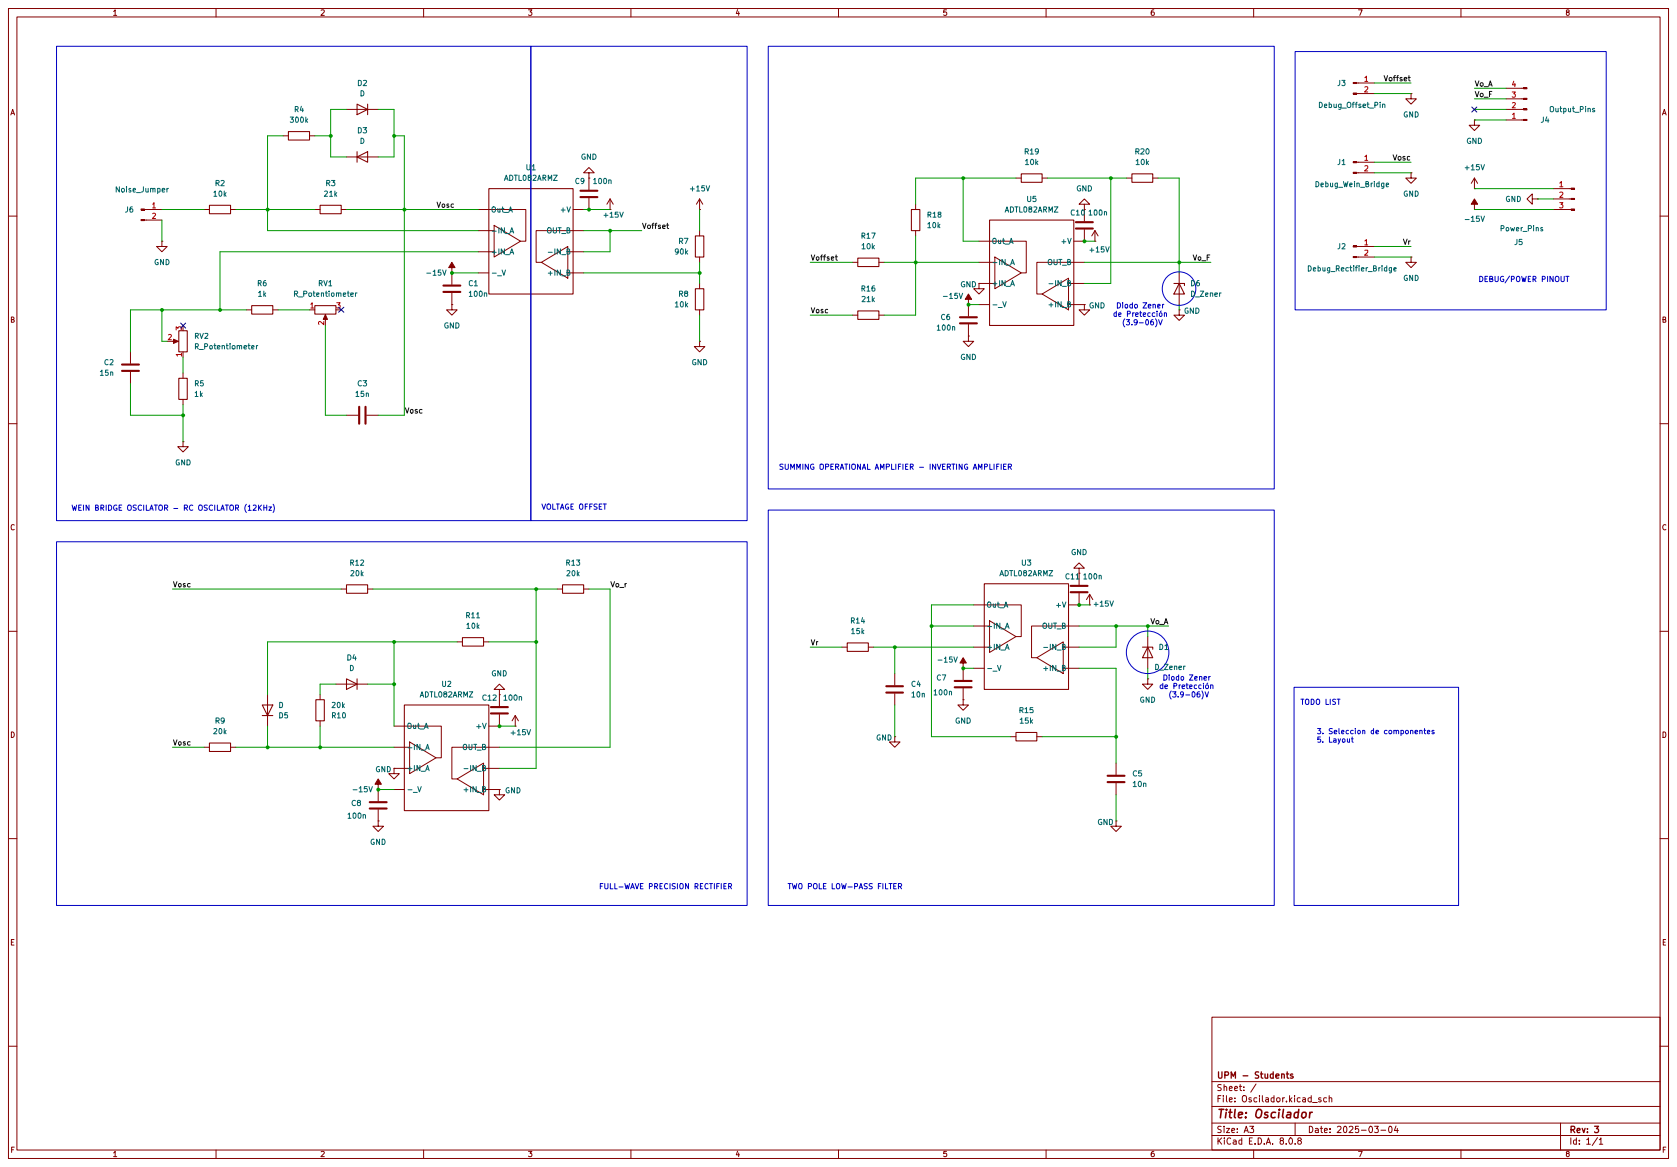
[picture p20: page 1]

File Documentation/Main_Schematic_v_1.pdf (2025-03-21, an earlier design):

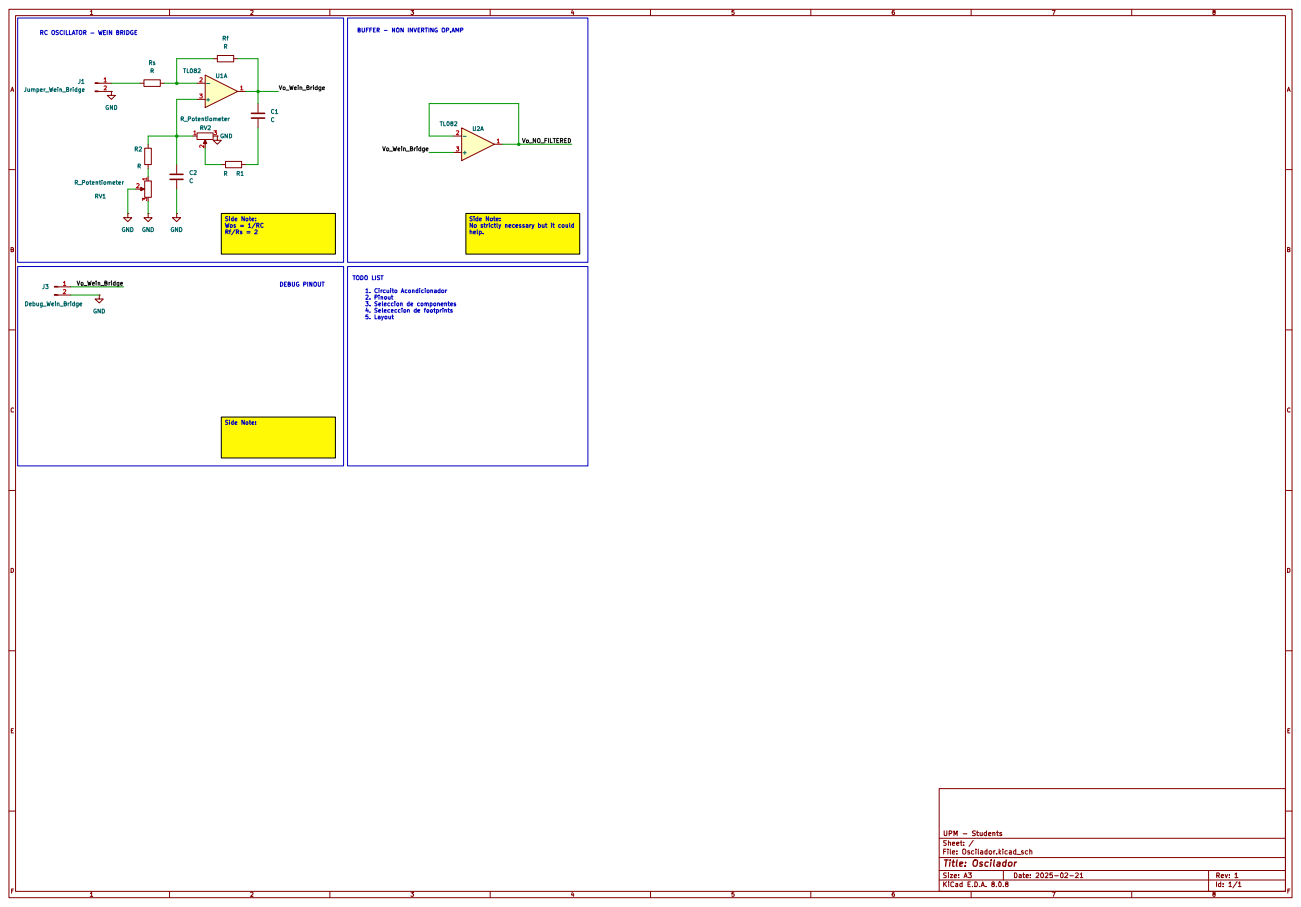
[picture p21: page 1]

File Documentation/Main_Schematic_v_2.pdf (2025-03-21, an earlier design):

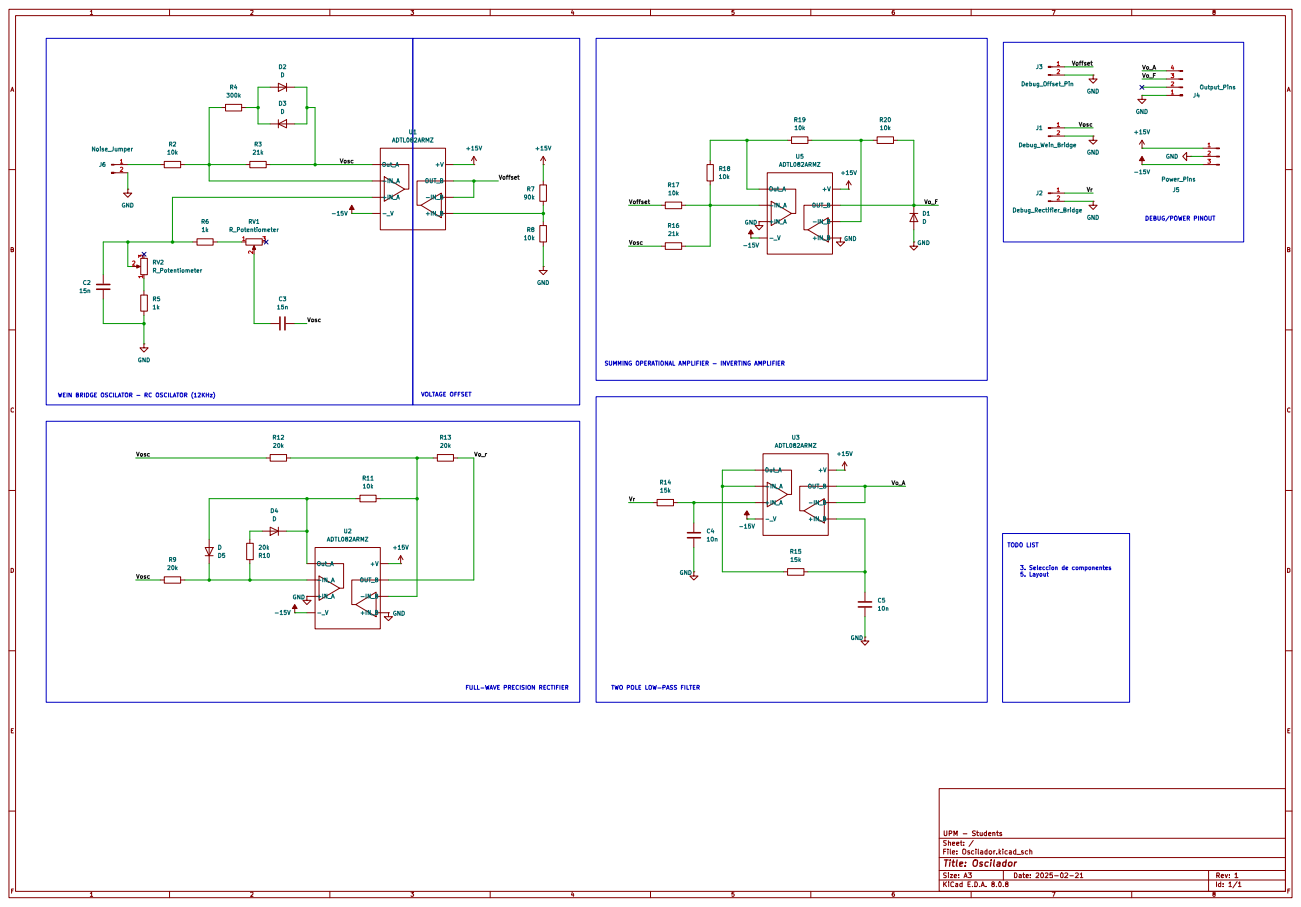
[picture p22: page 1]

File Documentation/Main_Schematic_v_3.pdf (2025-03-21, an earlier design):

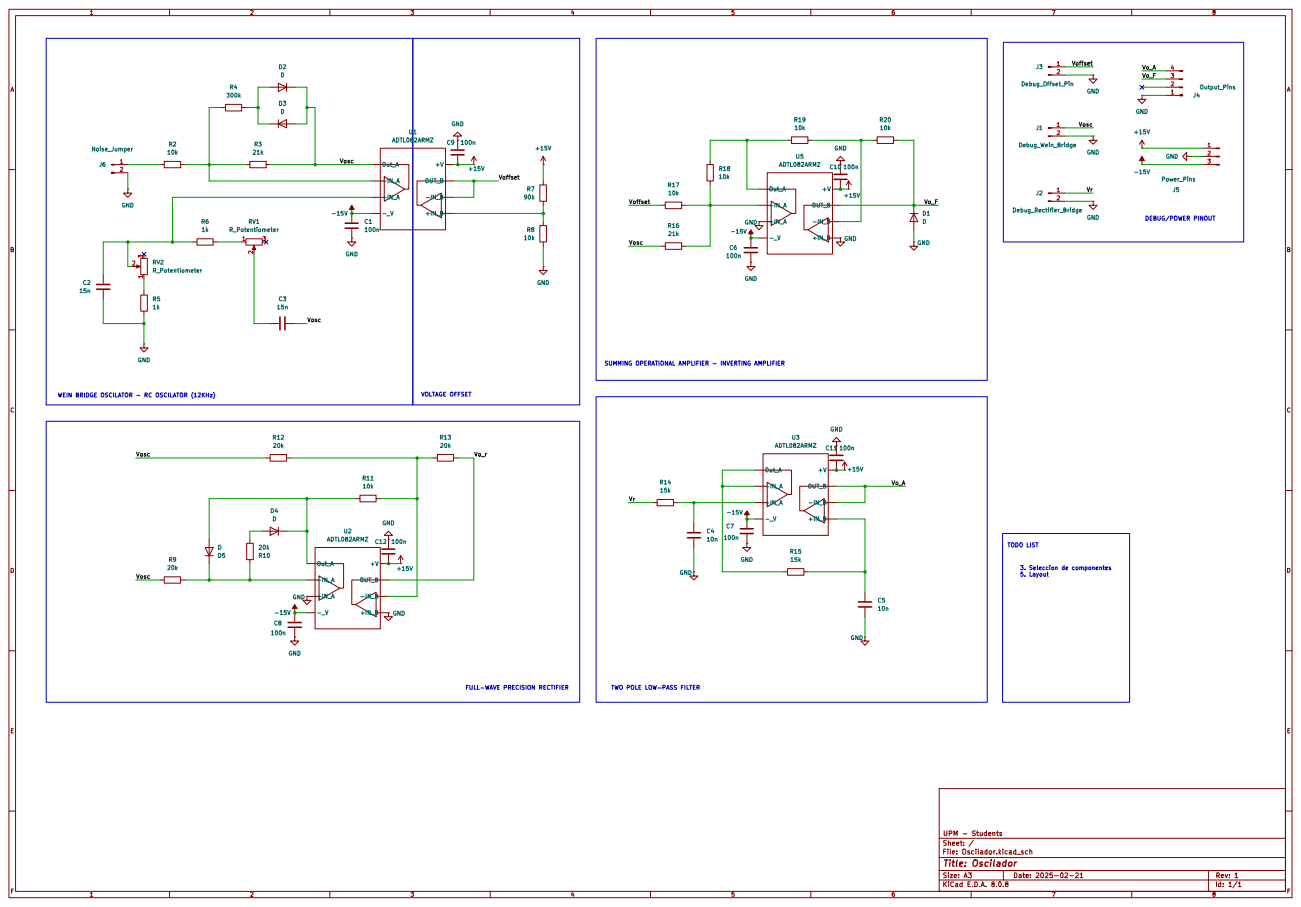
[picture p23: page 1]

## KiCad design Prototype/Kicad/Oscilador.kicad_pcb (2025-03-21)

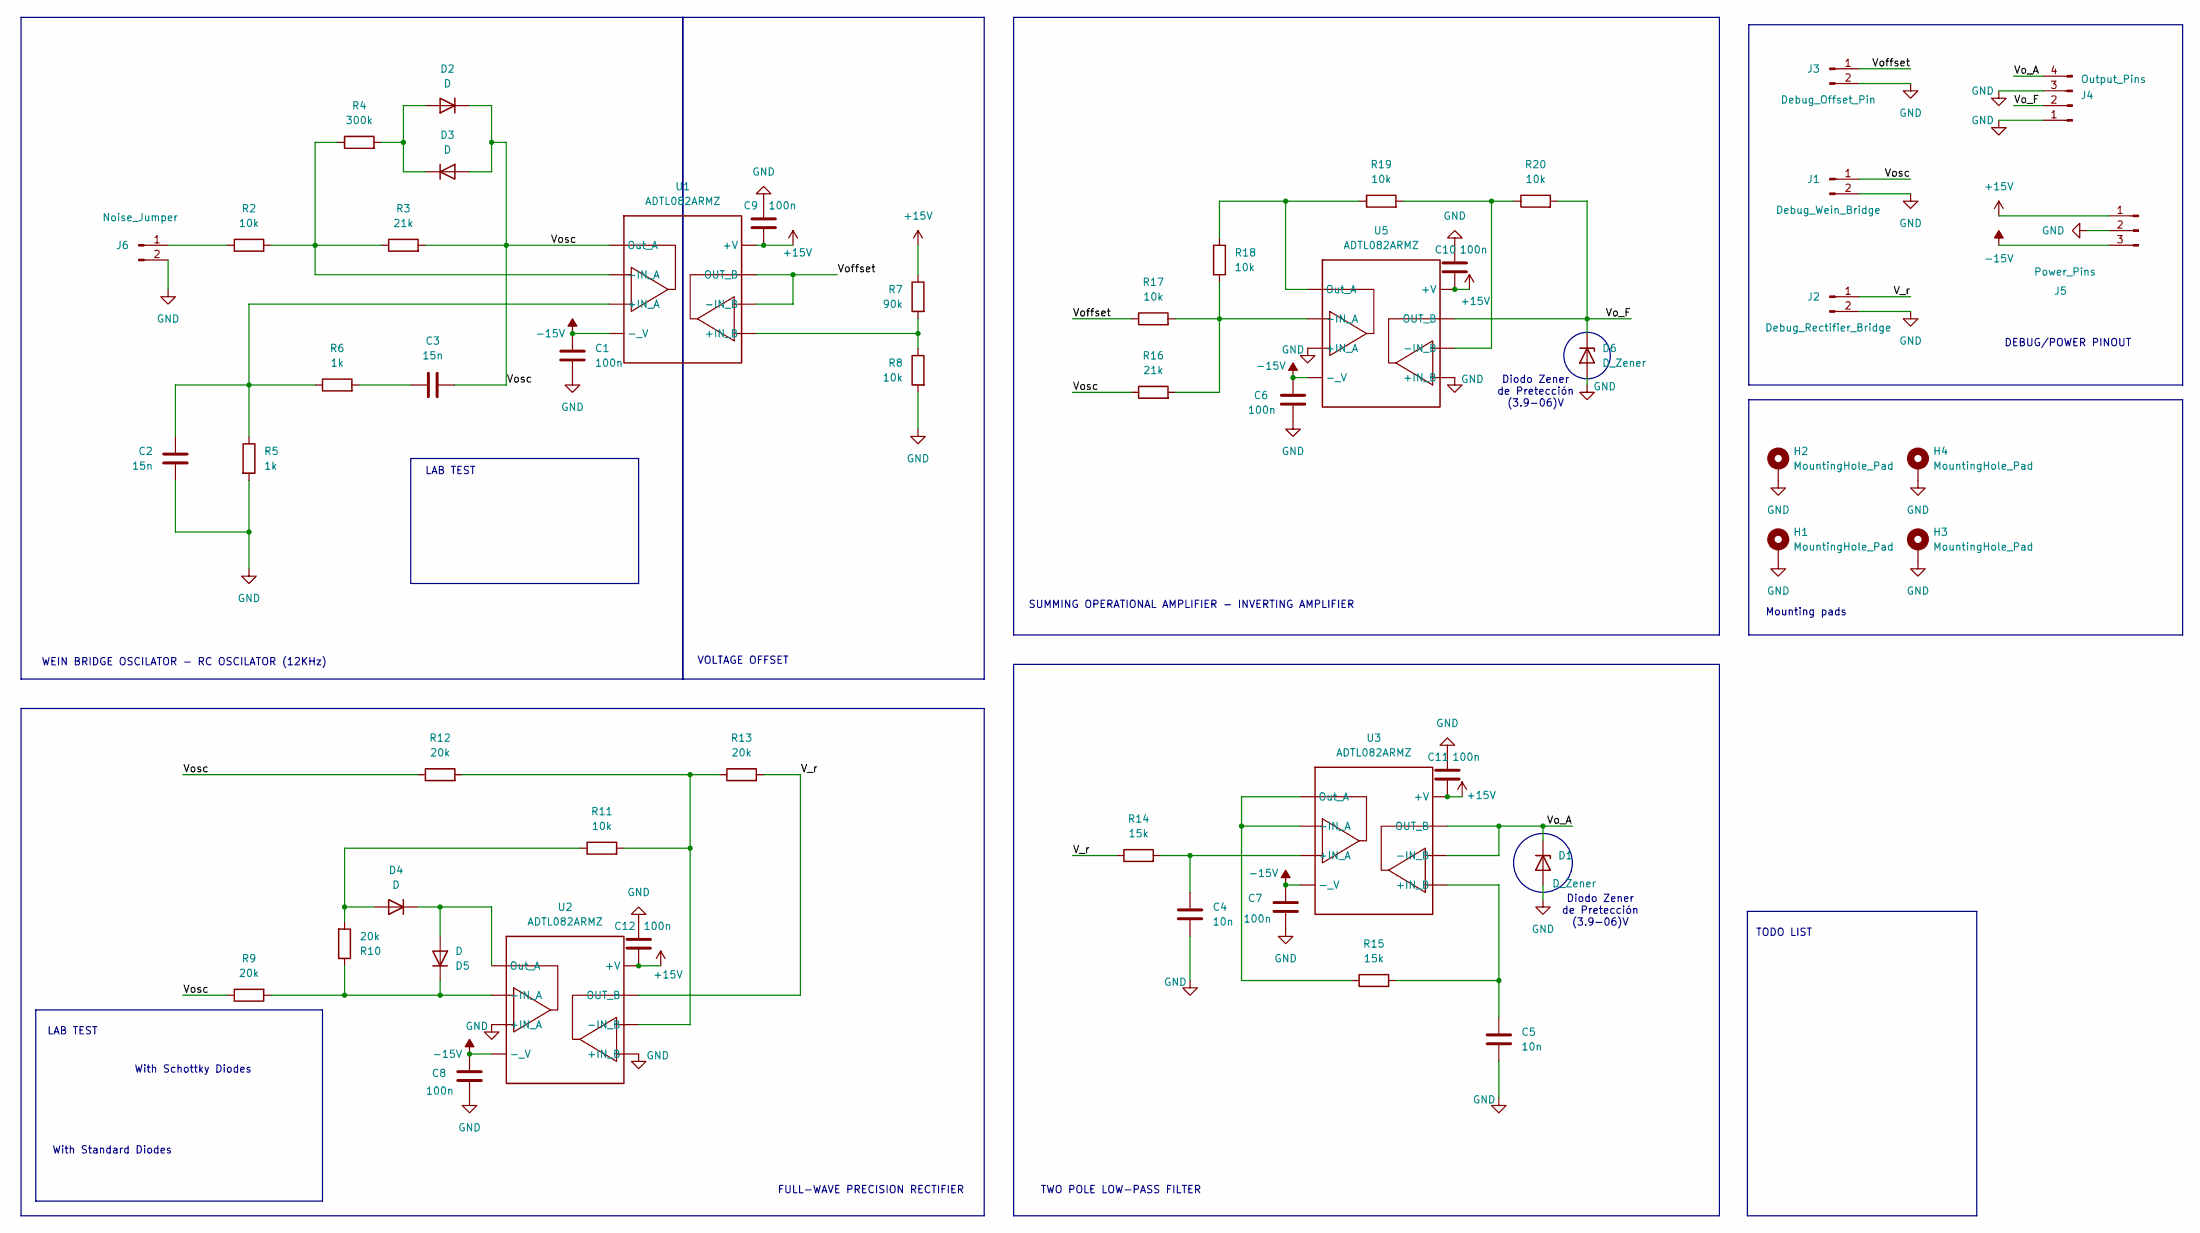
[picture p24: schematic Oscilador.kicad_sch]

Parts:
C1, C6, C7, C8, C9, C10, C11, C12: 100n; C_1206_3216Metric_Pad1.33x1.80mm_HandSolder
C2, C3: 15n; C_1206_3216Metric_Pad1.33x1.80mm_HandSolder
C4, C5: 10n; C_1206_3216Metric_Pad1.33x1.80mm_HandSolder
D1, D6: D_Zener; D_0805_2012Metric_Pad1.15x1.40mm_HandSolder
D2, D3, D4, D5: D; D_1206_3216Metric_Pad1.42x1.75mm_HandSolder
H1, H2, H3, H4: MountingHole_Pad; JLCPCB_Tooling_hole
J1: Debug_Wein_Bridge; PinHeader_1x02_P2.54mm_Vertical
J2: Debug_Rectifier_Bridge; PinHeader_1x02_P2.54mm_Vertical
J3: Debug_Offset_Pin; PinHeader_1x02_P2.54mm_Vertical
J4: Output_Pins; PinHeader_1x04_P2.54mm_Vertical
J5: Power_Pins; PinHeader_1x03_P2.54mm_Vertical
J6: Noise_Jumper; PinHeader_1x02_P2.54mm_Vertical
R2, R8, R11, R17, R18, R19, R20: 10k; R_1206_3216Metric_Pad1.30x1.75mm_HandSolder
R3, R16: 21k; R_1206_3216Metric_Pad1.30x1.75mm_HandSolder
R4: 300k; R_1206_3216Metric_Pad1.30x1.75mm_HandSolder
R5, R6: 1k; R_1206_3216Metric_Pad1.30x1.75mm_HandSolder
R7: 90k; R_1206_3216Metric_Pad1.30x1.75mm_HandSolder
R9, R10, R12, R13: 20k; R_1206_3216Metric_Pad1.30x1.75mm_HandSolder
R14, R15: 15k; R_1206_3216Metric_Pad1.30x1.75mm_HandSolder
U1, U2, U3, U5: ADTL082ARMZ; SOIC-8_3.9x4.9mm_P1.27mm

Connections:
+15V: C9.1, C10.1, C11.1, C12.1, J5.1, R7.1, U1.8 (+V), U2.8 (+V), U3.8 (+V), U5.8 (+V)
-15V: C1.2, C6.2, C7.2, C8.2, J5.3, U1.4 (-_V), U2.4 (-_V), U3.4 (-_V), U5.4 (-_V)
/V_r: J2.1, R13.2, R14.1, U2.7 (OUT_B)
/Vo_A: D1.1 (K), J4.4, U3.6 (-IN_B), U3.7 (OUT_B)
/Vo_F: D6.1 (K), J4.2, R20.2, U5.7 (OUT_B)
/Voffset: J3.1, R17.1, U1.6 (-IN_B), U1.7 (OUT_B)
/Vosc: C3.2, D2.1 (K), D3.2 (A), J1.1, R3.2, R9.1, R12.1, R16.1, U1.1 (Out_A)
GND: C1.1, C2.2, C4.2, C5.2, C6.1, C7.1, C8.1, C9.2, C10.2, C11.2, C12.2, D1.2 (A), D6.2 (A), H1.1, H2.1, H3.1, H4.1, J1.2, J2.2, J3.2, J4.1, J4.3, J5.2, J6.2, R5.2, R8.2, U2.3 (+IN_A), U2.5 (+IN_B), U5.3 (+IN_A), U5.5 (+IN_B)
unnamed: C3.1, R6.2
unnamed: D2.2 (A), D3.1 (K), R4.2
unnamed: D4.2 (A), R10.2, R11.1
unnamed: D4.1 (K), D5.2 (A), U2.1 (Out_A)
unnamed: D5.1 (K), R9.2, R10.1, U2.2 (-IN_A)
unnamed: J6.1, R2.1
unnamed: C2.1, R5.1, R6.1, U1.3 (+IN_A)
unnamed: R7.2, R8.1, U1.5 (+IN_B)
unnamed: R2.2, R3.1, R4.1, U1.2 (-IN_A)
unnamed: R11.2, R12.2, R13.1, U2.6 (-IN_B)
unnamed: C4.1, R14.2, U3.3 (+IN_A)
unnamed: C5.1, R15.2, U3.5 (+IN_B)
unnamed: R15.1, U3.1 (Out_A), U3.2 (-IN_A)
unnamed: R16.2, R17.2, R18.2, U5.2 (-IN_A)
unnamed: R19.2, R20.1, U5.6 (-IN_B)
unnamed: R18.1, R19.1, U5.1 (Out_A)

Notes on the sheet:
Mounting pads
Diodo Zener de Pretección (3.9-06)V
SUMMING OPERATIONAL AMPLIFIER - INVERTING AMPLIFIER
WEIN BRIDGE OSCILATOR - RC OSCILATOR (12KHz)
TODO LIST
With Schottky Diodes
With Standard Diodes
LAB TEST
FULL-WAVE PRECISION RECTIFIER
TWO POLE LOW-PASS FILTER
VOLTAGE OFFSET
DEBUG/POWER PINOUT

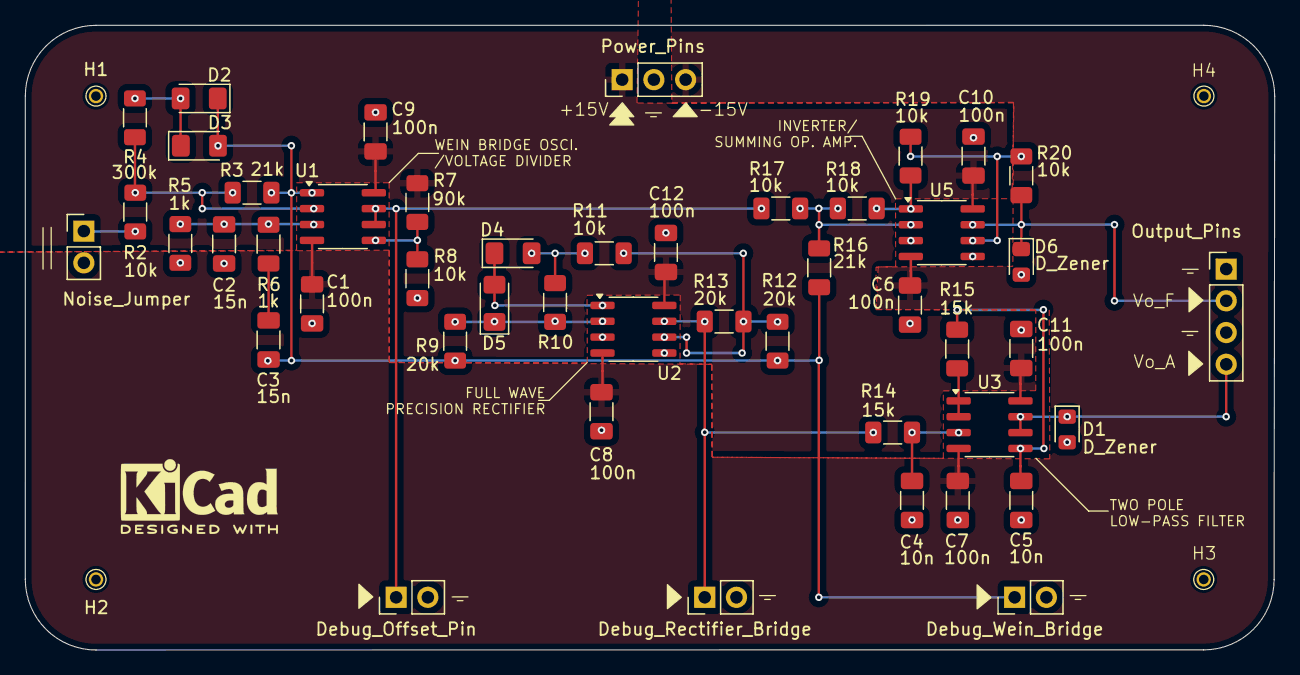
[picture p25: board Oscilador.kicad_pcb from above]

Board: 2 copper layers, 100.0 x 50.0 mm, 51 parts (0 on the bottom side), 24 nets.

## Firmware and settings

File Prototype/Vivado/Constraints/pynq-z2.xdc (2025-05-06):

## Clock
set_property -dict {PACKAGE_PIN H16 IOSTANDARD LVCMOS33} [get_ports {clk}];

## Reset - Switch 0 (placa rosa SW0)
set_property -dict {PACKAGE_PIN M20 IOSTANDARD LVCMOS33} [get_ports {reset}]

## Botones (placa rosa BTN0-BTN3)
#set_property -dict {PACKAGE_PIN D20 IOSTANDARD LVCMOS33} [get_ports {botones[2]}]
#set_property -dict {PACKAGE_PIN L20 IOSTANDARD LVCMOS33} [get_ports {botones[1]}]
#set_property -dict {PACKAGE_PIN L19 IOSTANDARD LVCMOS33} [get_ports {botones[0]}]

#Selectores Displays
# Disp4
set_property -dict { PACKAGE_PIN F20   IOSTANDARD LVCMOS33 } [get_ports { selector[0] }]; 
# Disp3
set_property -dict { PACKAGE_PIN U19   IOSTANDARD LVCMOS33 } [get_ports { selector[1] }]; 
# Disp2
set_property -dict { PACKAGE_PIN B19   IOSTANDARD LVCMOS33 } [get_ports { selector[2] }]; 
# Disp1
set_property -dict { PACKAGE_PIN B20   IOSTANDARD LVCMOS33 } [get_ports { selector[3] }]; 

#Segments
#--24 segment 0 (g)
set_property -dict { PACKAGE_PIN Y7    IOSTANDARD LVCMOS33 } [get_ports { segments[0] }]; 
#--20 segment 1 (f)
set_property -dict { PACKAGE_PIN A20   IOSTANDARD LVCMOS33 } [get_ports { segments[1] }]; 
#--14 segment 2 (e)
set_property -dict { PACKAGE_PIN V6    IOSTANDARD LVCMOS33 } [get_ports { segments[2] }];
#--15 segment 3 (d)
set_property -dict { PACKAGE_PIN Y6    IOSTANDARD LVCMOS33 } [get_ports { segments[3] }];
#--23 segment 4 (c)
set_property -dict { PACKAGE_PIN W6    IOSTANDARD LVCMOS33 } [get_ports { segments[4] }];
#--8  segment 5 (b)
set_property -dict { PACKAGE_PIN F19   IOSTANDARD LVCMOS33 } [get_ports { segments[5] }];
#--21 segment 6 (a)
set_property -dict { PACKAGE_PIN Y9    IOSTANDARD LVCMOS33 } [get_ports { segments[6] }];
#punto
set_property -dict { PACKAGE_PIN C20    IOSTANDARD LVCMOS33 } [get_ports { segments[7] }];

#LEDs
#set_property -dict { PACKAGE_PIN W18 IOSTANDARD LVCMOS33}  [get_ports {leds[0]}];
#set_property -dict { PACKAGE_PIN W19 IOSTANDARD LVCMOS33}  [get_ports {leds[1]}];
#set_property -dict { PACKAGE_PIN Y18 IOSTANDARD LVCMOS33}  [get_ports {leds[2]}]; 
#set_property -dict { PACKAGE_PIN U7  IOSTANDARD LVCMOS33 } [get_ports {leds[3]}]; 
#set_property -dict { PACKAGE_PIN V7  IOSTANDARD LVCMOS33 } [get_ports {leds[4]}];
#set_property -dict { PACKAGE_PIN U8  IOSTANDARD LVCMOS33 } [get_ports {leds[5]}];
#set_property -dict { PACKAGE_PIN V8  IOSTANDARD LVCMOS33 } [get_ports {leds[6]}]; 
#set_property -dict { PACKAGE_PIN V10 IOSTANDARD LVCMOS33 } [get_ports {leds[7]}];

# Entrada analogica
set_property -dict {PACKAGE_PIN E17 IOSTANDARD LVCMOS33} [get_ports vauxp1];
set_property -dict {PACKAGE_PIN D18 IOSTANDARD LVCMOS33} [get_ports vauxn1]; 

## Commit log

2025-03-21 Add basic structure of the proyect
    [Oscilador.kicad_pcb, Oscilador.kicad_sch]
2025-03-29 Adds information about the BOM
    [BOM.xlsx]
2025-05-01 Adds designs of the digital circuit
2025-05-06 Update the sources and include constrains of the board
